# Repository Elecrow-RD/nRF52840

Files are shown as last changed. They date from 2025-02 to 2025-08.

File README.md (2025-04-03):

### File introduction: 

#### firmware: here is the LR1110, LR1121, SX1262 & LLCC68 firmware file; 

#### lora_development_board: here is supporting the development of different modules of the board schematic diagrams, the user can download and use their own; 

#### sendATcommands_new: here is the lora send commands code program;

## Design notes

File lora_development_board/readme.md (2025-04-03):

### Corresponding modules use corresponding development boards: 

##### LR1262&LRCC68: the corresponding development board is Transceiver Module Dev Board (without MCU)_V0.1_SCH; 

##### nRFLRxxxx: the corresponding development board is Transceiver Module Dev Board (with Transceiver Module Dev Board (with MCU)_V0.1.

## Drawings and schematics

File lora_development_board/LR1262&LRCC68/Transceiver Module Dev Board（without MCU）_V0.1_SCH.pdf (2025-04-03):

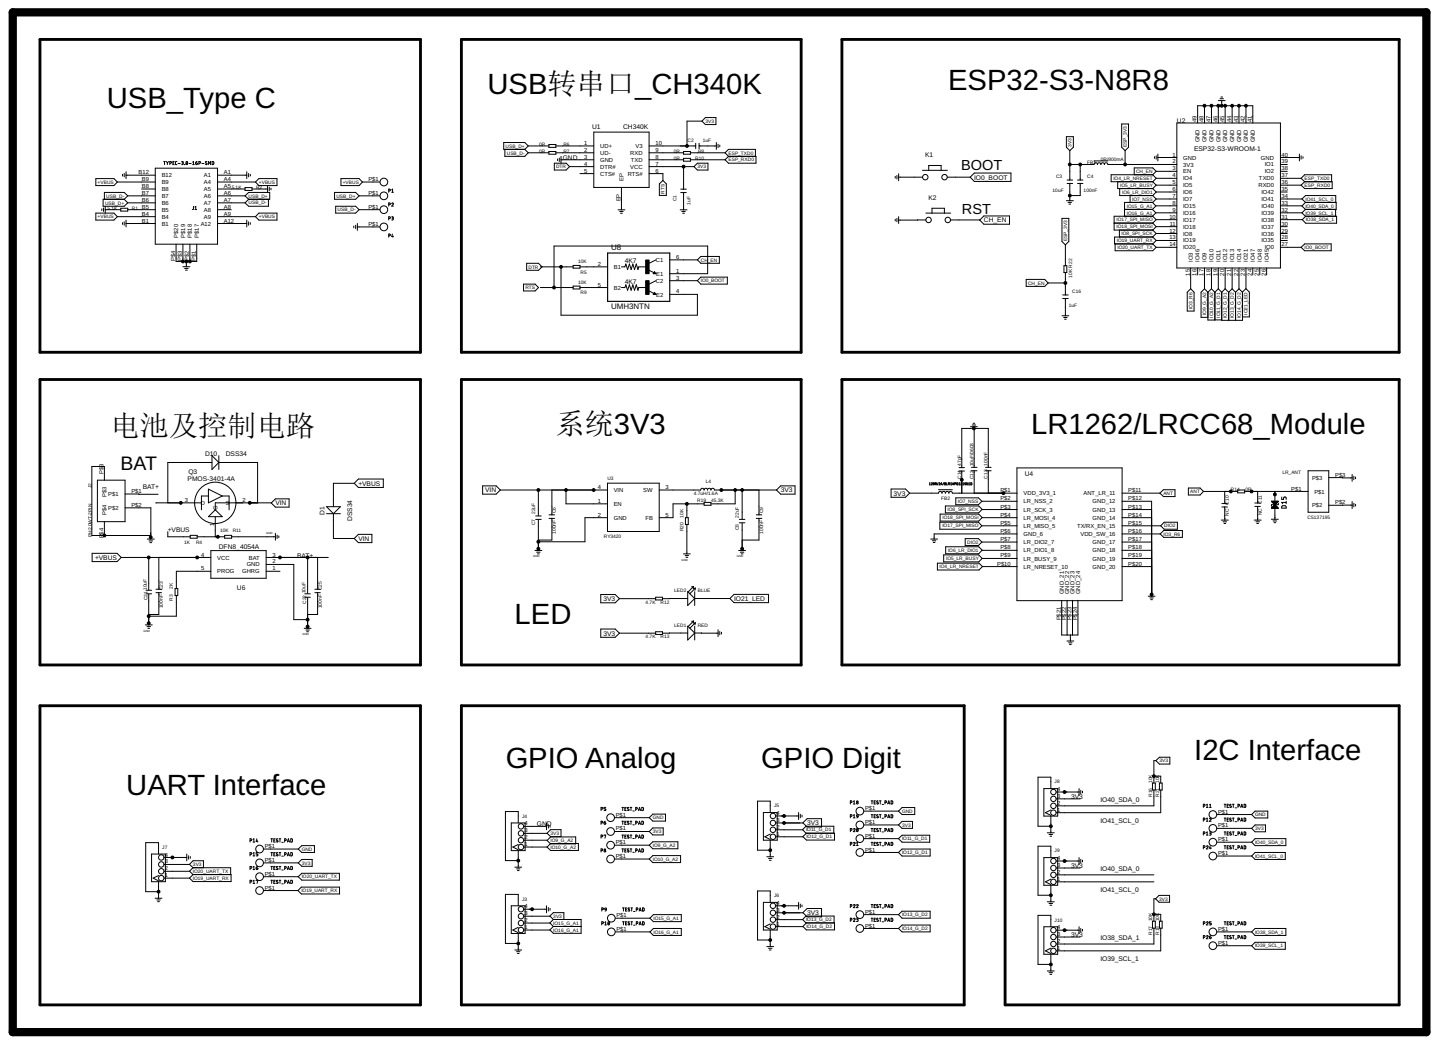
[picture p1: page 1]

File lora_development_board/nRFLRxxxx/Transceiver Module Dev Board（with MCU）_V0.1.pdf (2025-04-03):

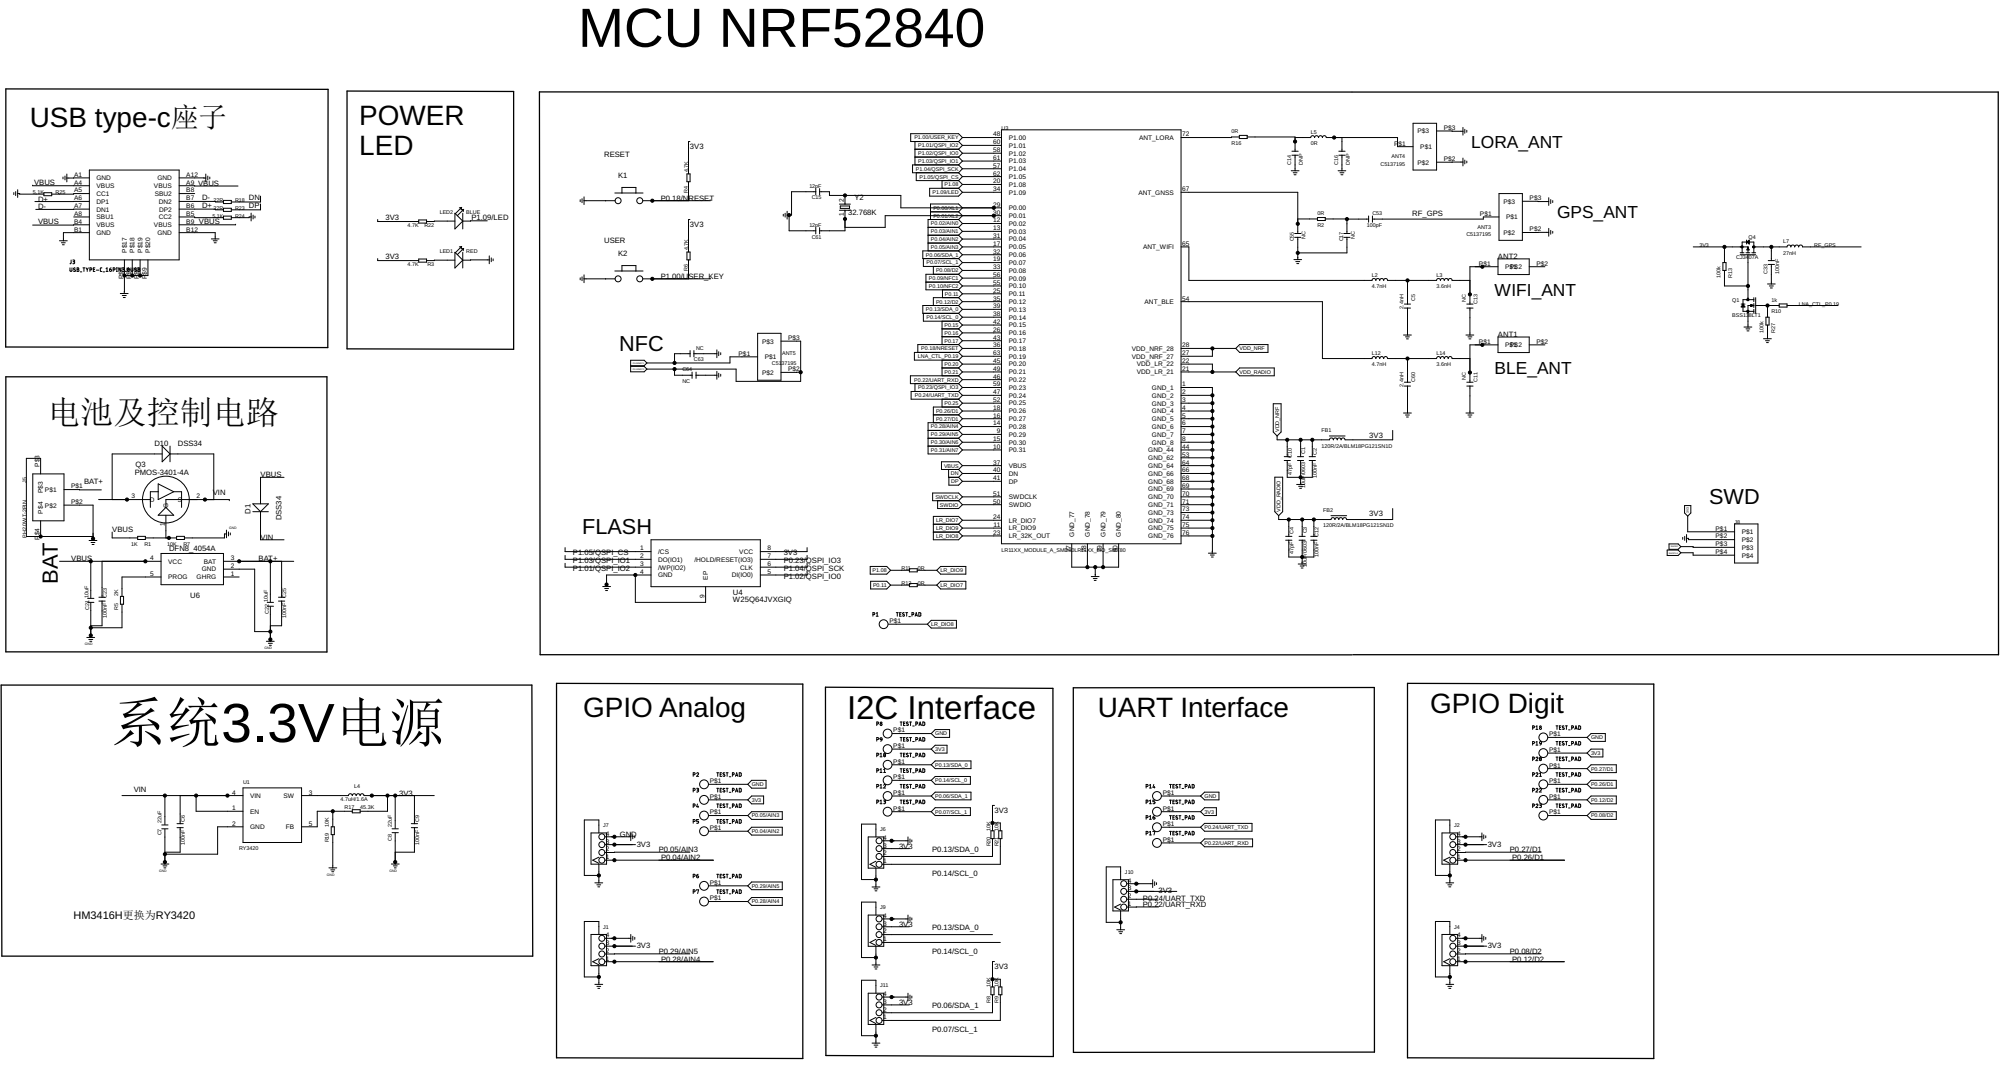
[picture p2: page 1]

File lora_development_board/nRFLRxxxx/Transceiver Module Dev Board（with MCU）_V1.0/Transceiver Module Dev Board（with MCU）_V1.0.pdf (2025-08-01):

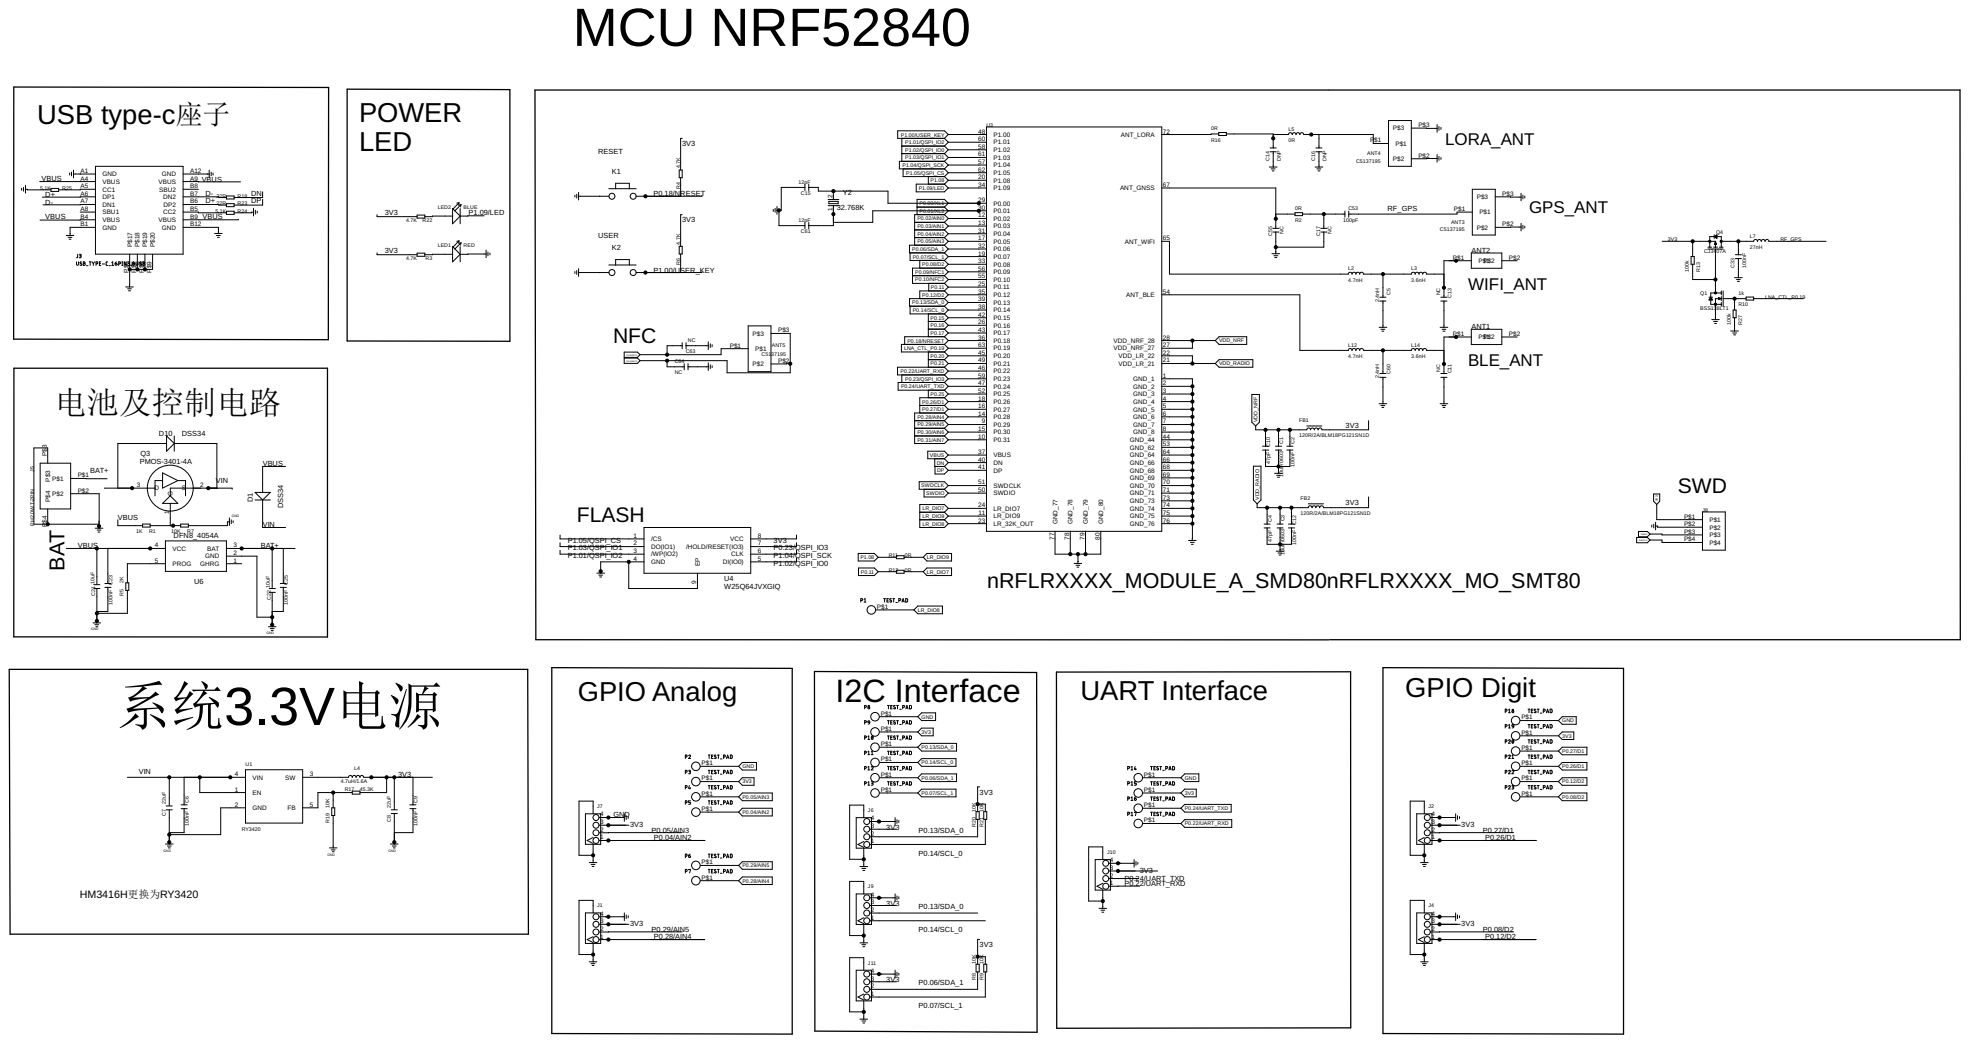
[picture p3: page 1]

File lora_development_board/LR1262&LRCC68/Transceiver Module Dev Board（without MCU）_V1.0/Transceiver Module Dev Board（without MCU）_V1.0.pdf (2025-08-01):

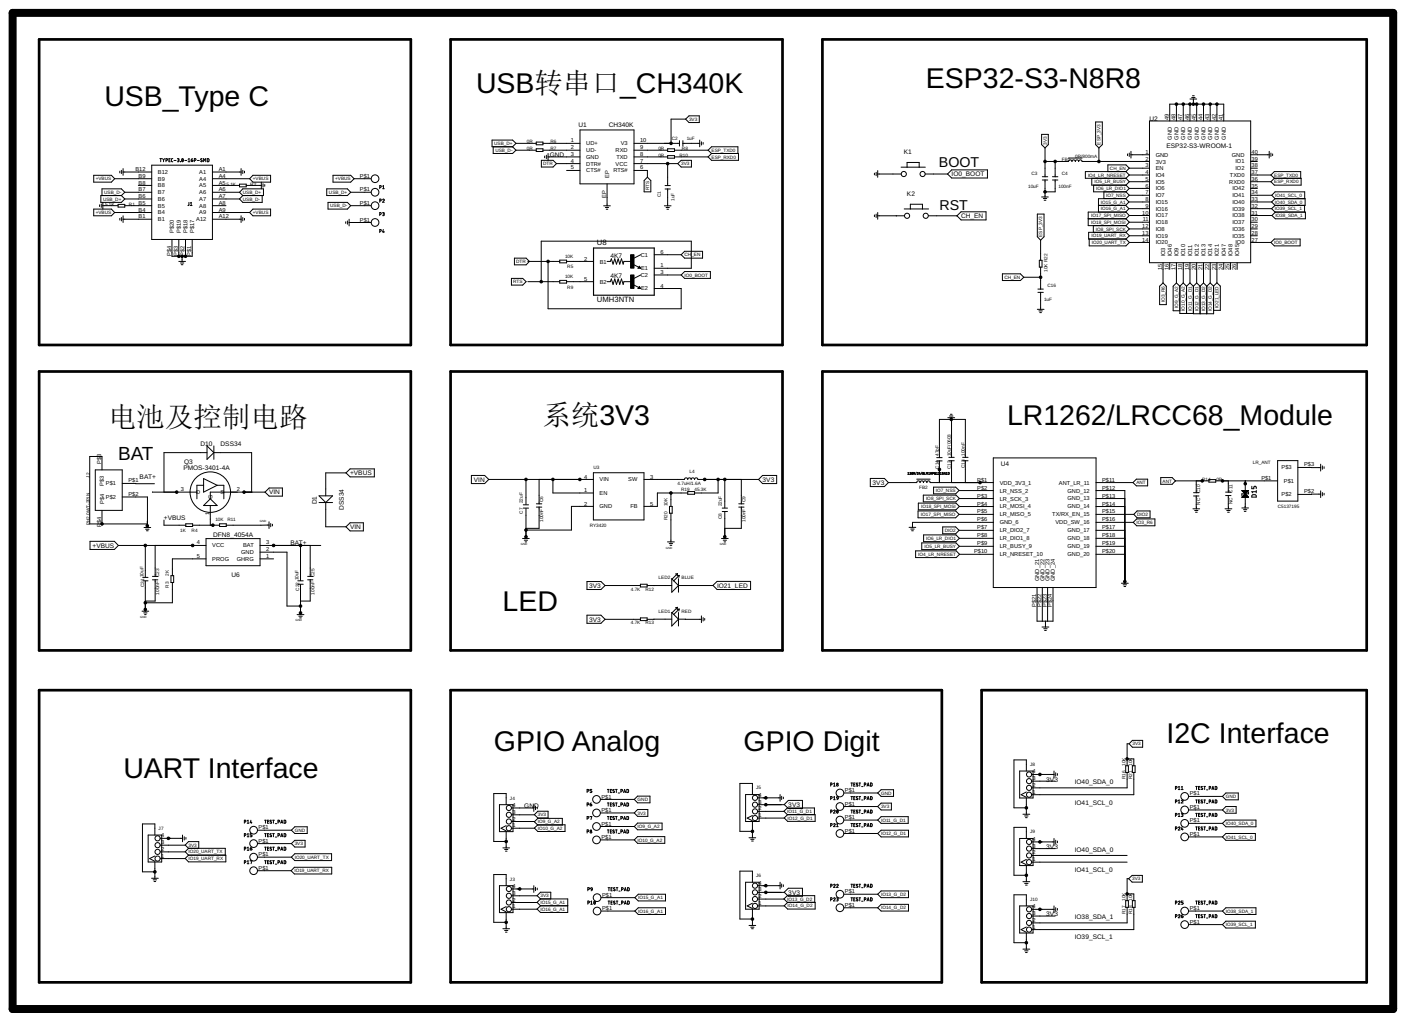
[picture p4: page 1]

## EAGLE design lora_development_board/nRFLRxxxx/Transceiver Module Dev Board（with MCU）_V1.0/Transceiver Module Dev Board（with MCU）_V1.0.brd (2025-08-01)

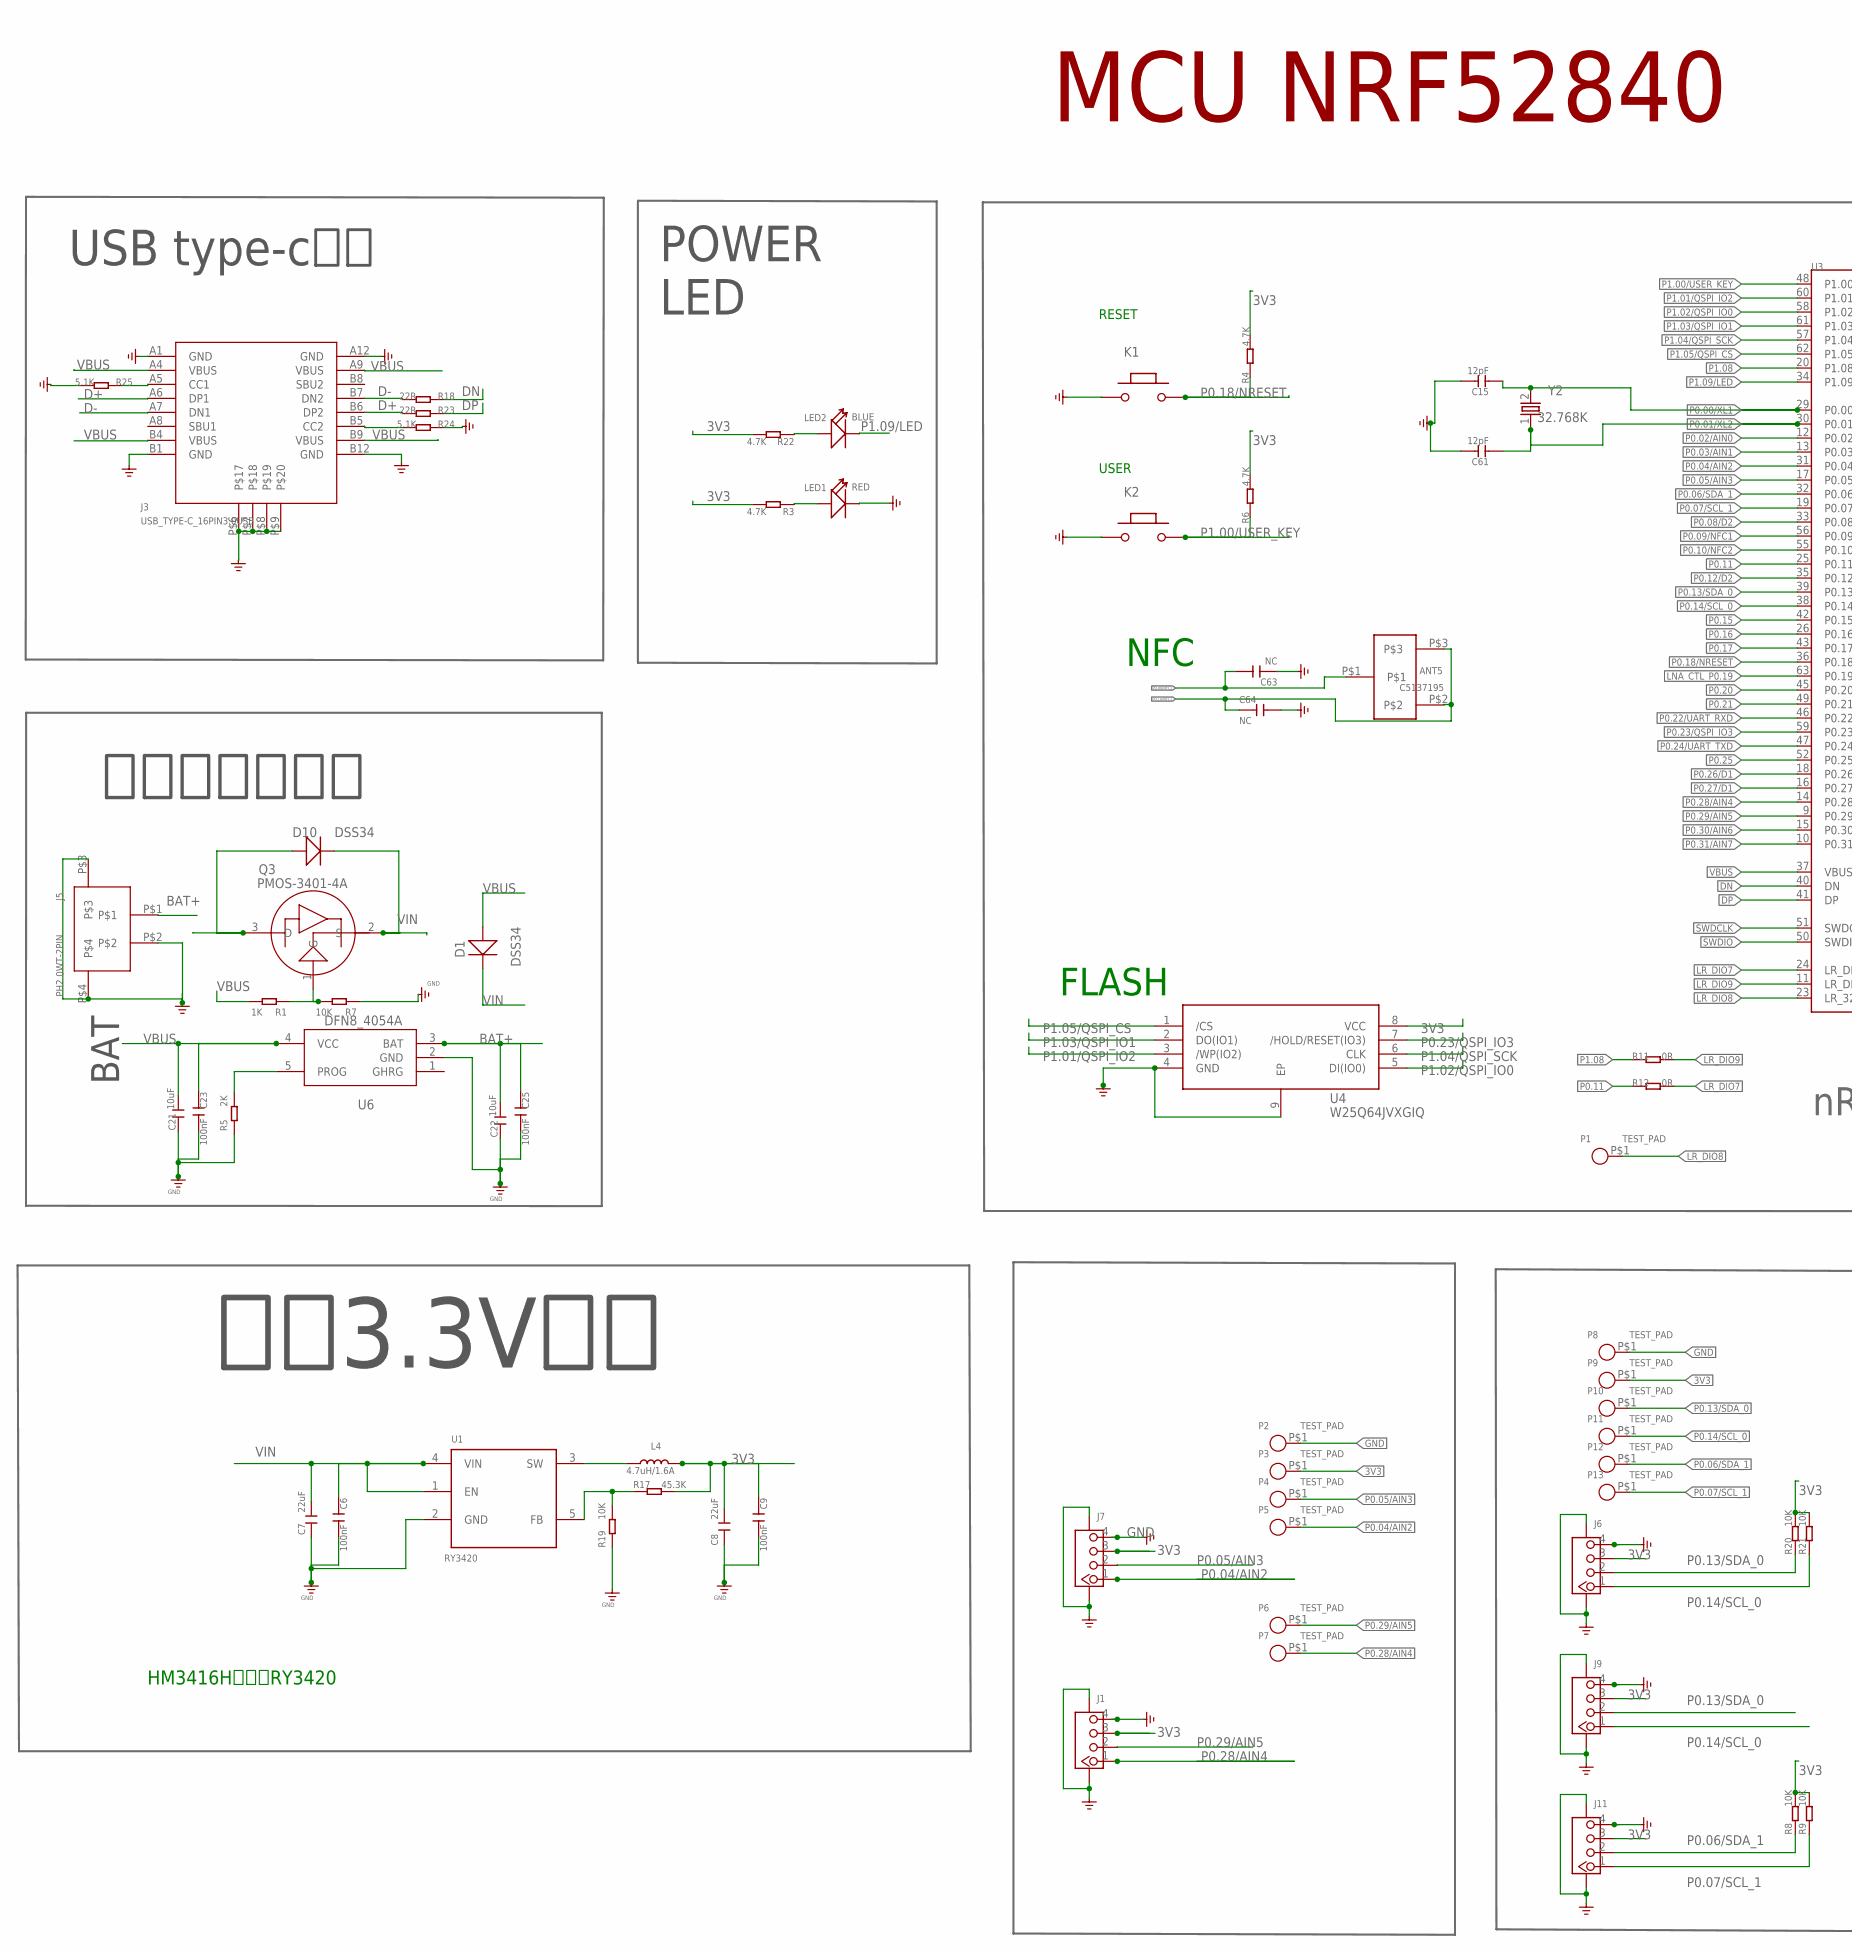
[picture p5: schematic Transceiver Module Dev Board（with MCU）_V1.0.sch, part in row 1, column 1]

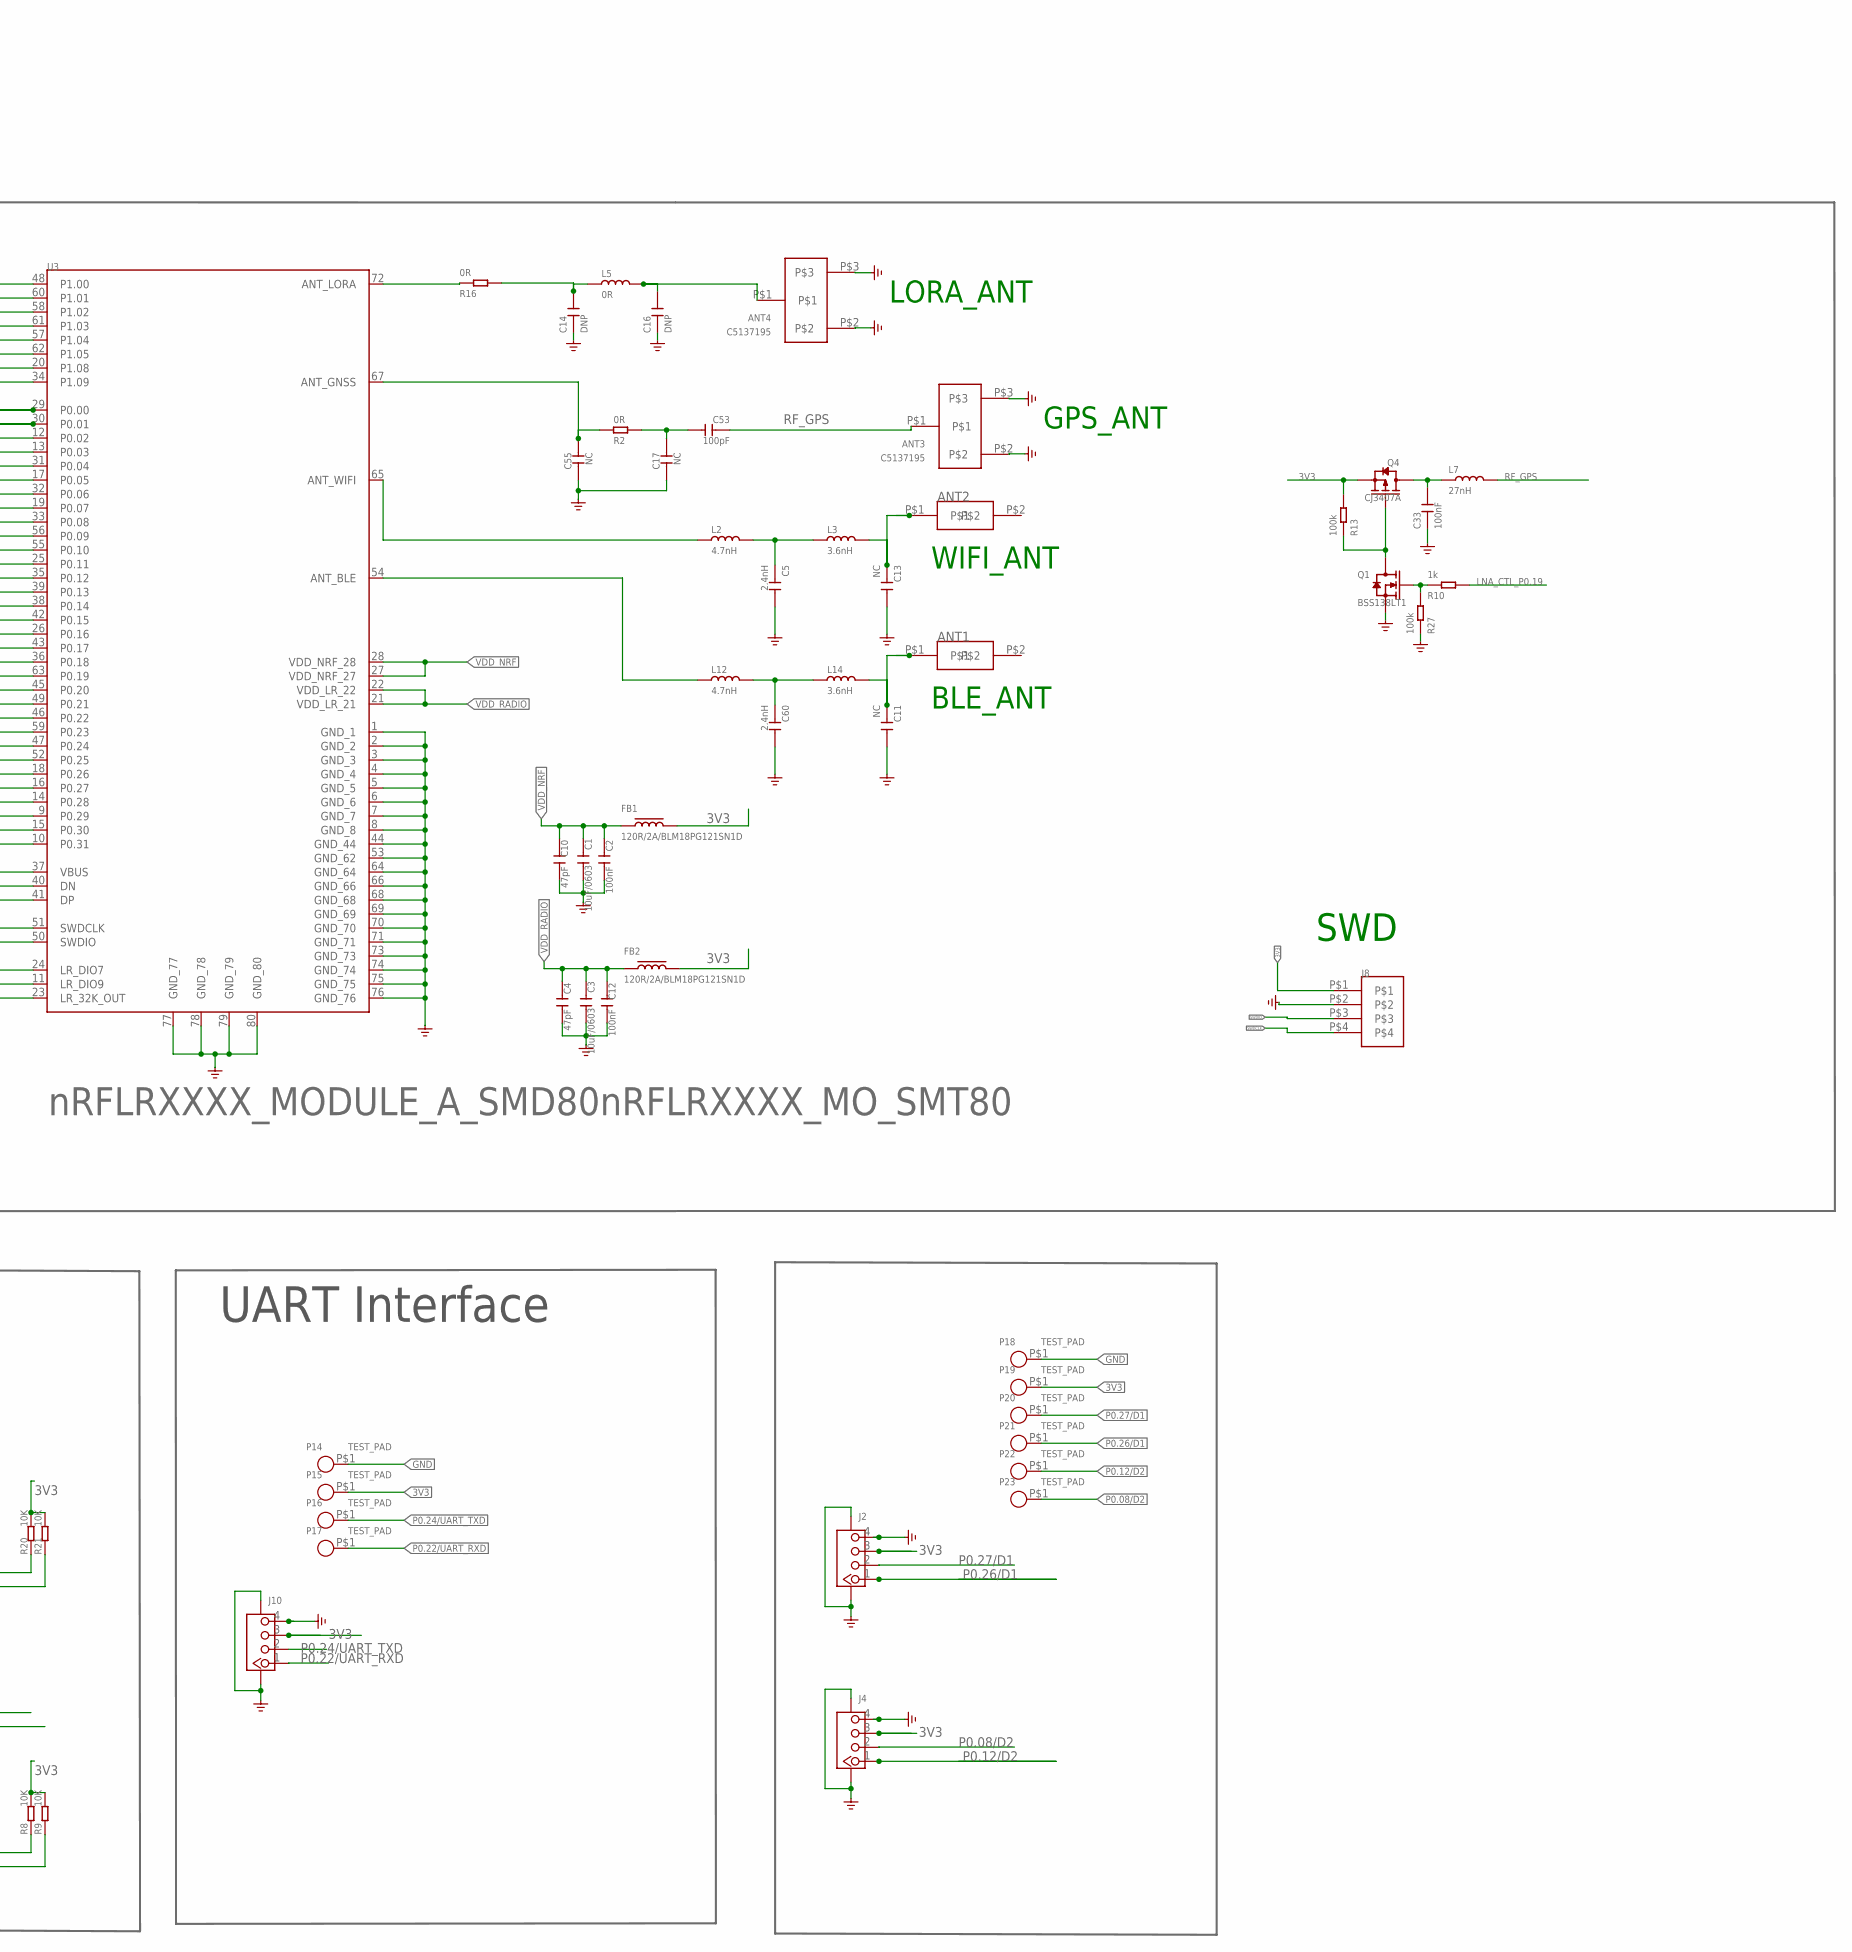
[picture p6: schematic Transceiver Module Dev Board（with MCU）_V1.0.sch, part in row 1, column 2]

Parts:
ANT1, ANT2: ANT2.4G_BLE; 2.4G_BLE
ANT3, ANT4, ANT5: C5137195; MYSELF_IPEX1
C1, C3: 10uF/0603; C0603
C2, C6, C9, C12, C23, C25, C33: 100nF; C0402
C4, C10: 47pF; C0402
C5, C60: 2.4nH; DISCRETE-NEW_C0402
C7, C8: 22uF; 0603
C11, C13, C17, C55, C63, C64: NC; DISCRETE-NEW_C0402
C14, C16: DNP; C0402
C15, C61: 12pF; DISCRETE-NEW_C0402
C21, C22: 10uF; 0402
C53: 100pF; DISCRETE-NEW_C0402
D1, D10: DSS34; D_SOD123FL
FB1, FB2: 120R/2A/BLM18PG121SN1D; L0603
J1, J2, J4, J6, J7, J9, J10, J11: CONNECTOR_TWIG-4P-2.0-SMD-FEMALE-REINFORCE90D; CONNECTOR_4P-SMD-2.0-90D
J3: USB_TYPE-C_16PIN3.0USB; KEVIN_3.0TYPEC-SMD
J5: PH2.0WT-2PIN
J8: 2.0MM-4P
K1, K2: BUTTON; 157SW
L2, L12: 4.7nH; XADOW-GPS-V2_DISCRETE-NEW_L0402
L3, L14: 3.6nH; XADOW-GPS-V2_DISCRETE-NEW_L0402
L4: 4.7uH/1.6A; A9G_DISCRETE_L0805
L5: 0R; L0402
L7: 27nH; L0402
LED1: RED; DISCRETE_LED-0603
LED2: BLUE; DISCRETE_LED-0603
P1, P2, P3, P4, P5, P6, P7, P8, P9, P10, P11, P12, P13, P14, P15, P16, P17, P18, P19, P20, P21, P22, P23: TEST_PAD; TEST_PAD-1.5MM
Q1: BSS138LT1; SOT-323
Q3: PMOS-3401-4A; SOT-23
Q4: CJ3407A; SOT-323
R1: 1K; 0402
R2, R16: 0R; DISCRETE-NEW_R0402
R3, R22: 4.7K; 0402
R4, R6: 4.7K; DISCRETE_R0603
R5: 2K; 0402
R7, R8, R9, R19, R20, R21: 10K; 0402
R10: 1k; R0402
R11, R12: 0R; R0402
R13, R27: 100k; R0402
R17: 45.3K; 0402
R18, R23: 22R; 0402
R24, R25: 5.1K; 0402
U1: RY3420; CROWBOT_-V1.0-20220525_A_XBJ_SOT23-5
U3: nRFLRXXXX_MODULE_A_SMD80nRFLRXXXX_MO_SMT80; LR11XX_MO_A_SMD80
U4: W25Q64JVXGIQ; XSON-EP(4×4)
U6: DFN8_4054A; DFN8_SOP23-5
Y2: 32.768K; NORDIC_NRF_XTAL_3215_N

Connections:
3V3: C8.2, C9.1, FB1.2, FB2.2, J1.3, J2.3, J4.3, J6.3, J7.3, J8.P$1, J9.3, J10.3, J11.3, L4.2, P3.P$1, P9.P$1, P15.P$1, P19.P$1, Q4.2 (S), R3.2, R4.2, R6.2, R8.2, R9.2, R13.2, R17.2, R20.2, R21.2, R22.2, U4.8 (VCC)
BAT+: C22.2, C25.1, D10.+, J5.P$1, Q3.3 (D), U6.3 (BAT)
D+: J3.A6 (DP1), J3.B6 (DP2), R23.2
D-: J3.A7 (DN1), J3.B7 (DN2), R18.2
DN: R18.1, U3.40 (DN)
DP: R23.1, U3.41 (DP)
GND: ANT3.P$2, ANT3.P$3, ANT4.P$2, ANT4.P$3, C1.2, C2.2, C3.2, C4.2, C5.2, C6.2, C7.1, C8.1, C9.2, C10.2, C11.2, C12.2, C13.2, C14.1, C15.2, C16.1, C17.2, C21.1, C22.1, C23.2, C25.2, C33.1, C55.2, C60.2, C61.2, C63.1, C64.2, J1.4, J1.SS1, J1.SS2, J2.4, J2.SS1, J2.SS2, J3.A1 (GND), J3.A12 (GND), J3.B1 (GND), J3.B12 (GND), J3.P$6, J3.P$7, J3.P$8, J3.P$9, J4.4, J4.SS1, J4.SS2, J5.P$2, J5.P$3, J5.P$4, J6.4, J6.SS1, J6.SS2, J7.4, J7.SS1, J7.SS2, J8.P$2, J9.4, J9.SS1, J9.SS2, J10.4, J10.SS1, J10.SS2, J11.4, J11.SS1, J11.SS2, K1.1, K2.1, LED1.-, P2.P$1, P8.P$1, P14.P$1, P18.P$1, Q1.2 (S), R5.1, R7.1, R19.1, R24.1, R25.2, R27.1, U1.2 (GND), U3.1 (GND_1), U3.2 (GND_2), U3.3 (GND_3), U3.4 (GND_4), U3.5 (GND_5), U3.6 (GND_6), U3.7 (GND_7), U3.8 (GND_8), U3.44 (GND_44), U3.53 (GND_62), U3.64 (GND_64), U3.66 (GND_66), U3.68 (GND_68), U3.69 (GND_69), U3.70 (GND_70), U3.71 (GND_71), U3.73 (GND_73), U3.74 (GND_74), U3.75 (GND_75), U3.76 (GND_76), U3.77 (GND_77), U3.78 (GND_78), U3.79 (GND_79), U3.80 (GND_80), U4.4 (GND), U4.9 (EP), U6.2 (GND)
LNA_CTL_P0.19: R10.2, U3.63 (P0.19)
LR_DIO7: R12.2, U3.24 (LR_DIO7)
LR_DIO8: P1.P$1, U3.23 (LR_32K_OUT)
LR_DIO9: R11.2, U3.11 (LR_DIO9)
unnamed: LED2.+, R22.1
unnamed: L12.1, U3.54 (ANT_BLE)
unnamed: C5.1, L2.2, L3.1
unnamed: ANT2.P$1, C13.1, L3.2
unnamed: L2.1, U3.65 (ANT_WIFI)
unnamed: J3.B5 (CC2), R24.2
unnamed: C55.1, R2.1, U3.67 (ANT_GNSS)
unnamed: R16.1, U3.72 (ANT_LORA)
unnamed: LED1.+, R3.1
unnamed: Q3.1 (G), R1.1, R7.2
unnamed: J3.A5 (CC1), R25.1
unnamed: L4.1, U1.3 (SW)
unnamed: C14.2, L5.1, R16.2
unnamed: ANT4.P$1, C16.2, L5.2
unnamed: Q1.3 (D), Q4.1 (G), R13.1
unnamed: Q1.1 (G), R10.1, R27.2
unnamed: R17.1, R19.2, U1.5 (FB)
unnamed: R5.2, U6.5 (PROG)
unnamed: C33.2, L7.1, Q4.3 (D)
unnamed: C17.1, C53.2, R2.2
unnamed: C60.1, L12.2, L14.1
unnamed: ANT1.P$1, C11.1, L14.2
P0.00/XL1: C15.1, U3.29 (P0.00), Y2.2
P0.01/XL2: C61.1, U3.30 (P0.01), Y2.1
P0.02/AIN0: U3.12 (P0.02)
P0.03/AIN1: U3.13 (P0.03)
P0.04/AIN2: J7.1, P5.P$1, U3.31 (P0.04)
P0.05/AIN3: J7.2, P4.P$1, U3.17 (P0.05)
P0.06/SDA_1: J11.2, P12.P$1, R8.1, U3.32 (P0.06)
P0.07/SCL_1: J11.1, P13.P$1, R9.1, U3.19 (P0.07)
P0.08/D2: J4.2, P23.P$1, U3.33 (P0.08)
P0.09/NFC1: ANT5.P$1, C63.2, U3.56 (P0.09)
P0.10/NFC2: ANT5.P$2, ANT5.P$3, C64.1, U3.55 (P0.10)
P0.11: R12.1, U3.25 (P0.11)
P0.12/D2: J4.1, P22.P$1, U3.35 (P0.12)
P0.13/SDA_0: J6.2, J9.2, P10.P$1, R20.1, U3.39 (P0.13)
P0.14/SCL_0: J6.1, J9.1, P11.P$1, R21.1, U3.38 (P0.14)
P0.15: U3.42 (P0.15)
P0.16: U3.26 (P0.16)
P0.17: U3.43 (P0.17)
P0.18/NRESET: K1.2, R4.1, U3.36 (P0.18)
P0.20: U3.45 (P0.20)
P0.21: U3.49 (P0.21)
P0.22/UART_RXD: J10.1, P17.P$1, U3.46 (P0.22)
P0.23/QSPI_IO3: U3.59 (P0.23), U4.7 (/HOLD/RESET(IO3))
P0.24/UART_TXD: J10.2, P16.P$1, U3.47 (P0.24)
P0.25: U3.52 (P0.25)
P0.26/D1: J2.1, P21.P$1, U3.18 (P0.26)
P0.27/D1: J2.2, P20.P$1, U3.16 (P0.27)
P0.28/AIN4: J1.1, P7.P$1, U3.14 (P0.28)
P0.29/AIN5: J1.2, P6.P$1, U3.9 (P0.29)
P0.30/AIN6: U3.15 (P0.30)
P0.31/AIN7: U3.10 (P0.31)
P1.00/USER_KEY: K2.2, R6.1, U3.48 (P1.00)
P1.01/QSPI_IO2: U3.60 (P1.01), U4.3 (/WP(IO2))
P1.02/QSPI_IO0: U3.58 (P1.02), U4.5 (DI(IO0))
P1.03/QSPI_IO1: U3.61 (P1.03), U4.2 (DO(IO1))
P1.04/QSPI_SCK: U3.57 (P1.04), U4.6 (CLK)
P1.05/QSPI_CS: U3.62 (P1.05), U4.1 (/CS)
P1.08: R11.1, U3.20 (P1.08)
P1.09/LED: LED2.-, U3.34 (P1.09)
RF_GPS: ANT3.P$1, C53.1, L7.2
SWDCLK: J8.P$4, U3.51 (SWDCLK)
SWDIO: J8.P$3, U3.50 (SWDIO)
VBUS: C21.2, C23.1, D1.+, J3.A4 (VBUS), J3.A9 (VBUS), J3.B4 (VBUS), J3.B9 (VBUS), R1.2, U3.37 (VBUS), U6.4 (VCC)
VDD_NRF: C1.1, C2.1, C10.1, FB1.1, U3.27 (VDD_NRF_27), U3.28 (VDD_NRF_28)
VDD_RADIO: C3.1, C4.1, C12.1, FB2.1, U3.21 (VDD_LR_21), U3.22 (VDD_LR_22)
VIN: C6.1, C7.2, D1.-, D10.-, Q3.2 (S), U1.1 (EN), U1.4 (VIN)

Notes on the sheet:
系统3.3V电源
UART Interface
MCU NRF52840
USB type-c座子
电池及控制电路
POWER LED
HM3416H更换为RY3420
BAT
FLASH
BLE_ANT
RESET
USER
WIFI_ANT
SWD
GPS_ANT
LORA_ANT
NFC

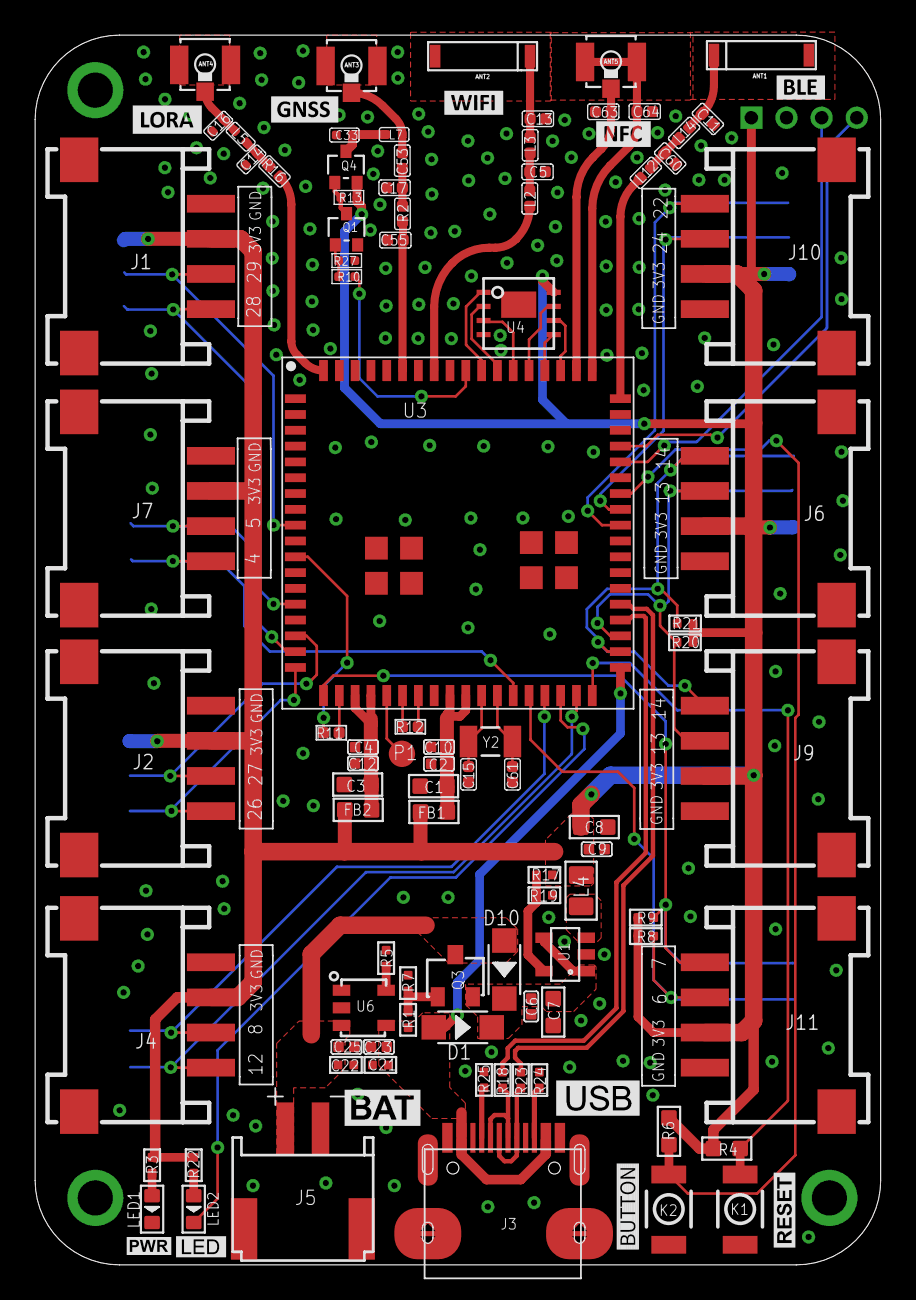
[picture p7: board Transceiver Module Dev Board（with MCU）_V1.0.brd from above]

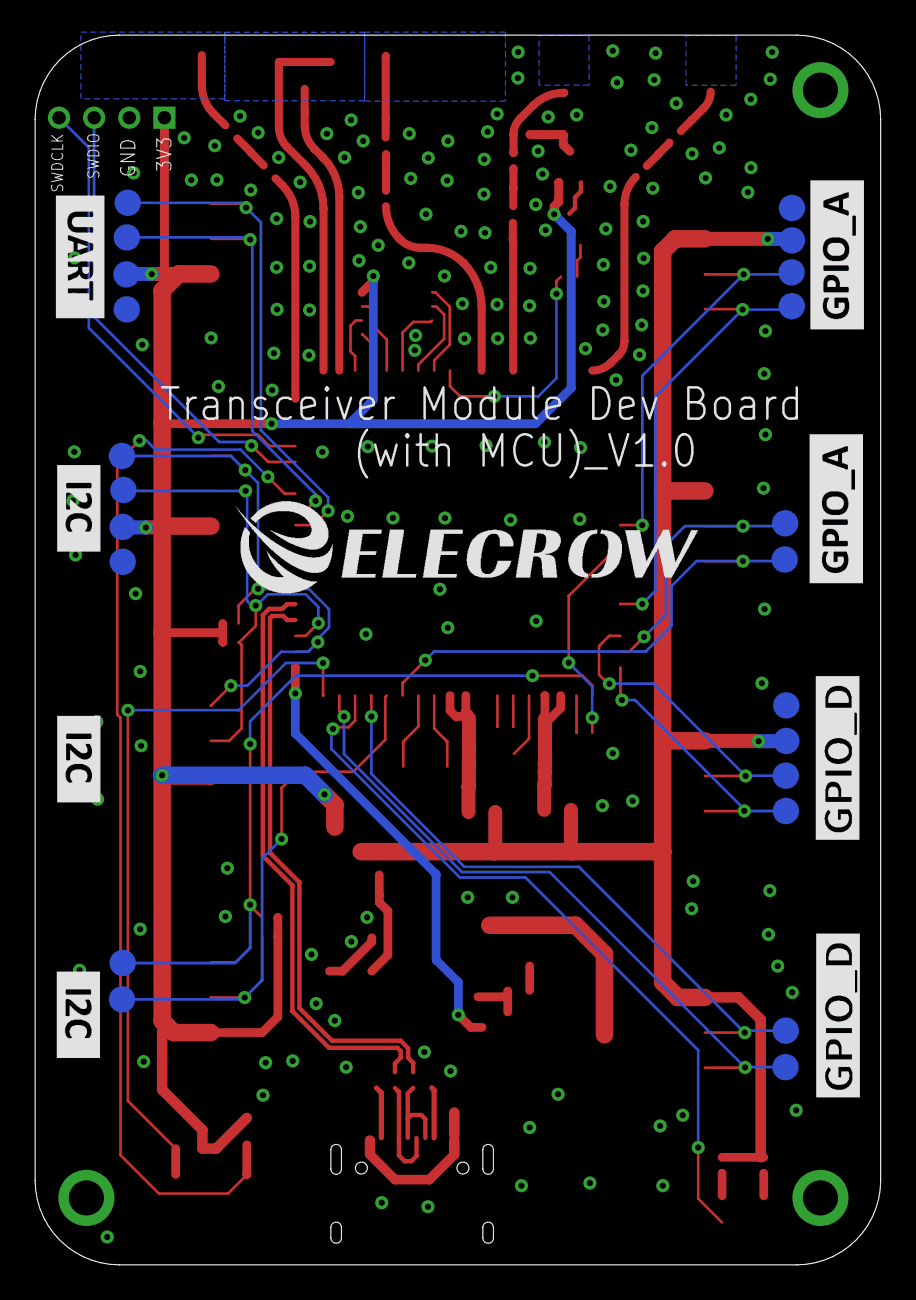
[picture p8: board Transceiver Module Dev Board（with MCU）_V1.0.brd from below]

Board: 2 copper layers, 48.1 x 70.0 mm, 114 parts (22 on the bottom side), 69 nets.

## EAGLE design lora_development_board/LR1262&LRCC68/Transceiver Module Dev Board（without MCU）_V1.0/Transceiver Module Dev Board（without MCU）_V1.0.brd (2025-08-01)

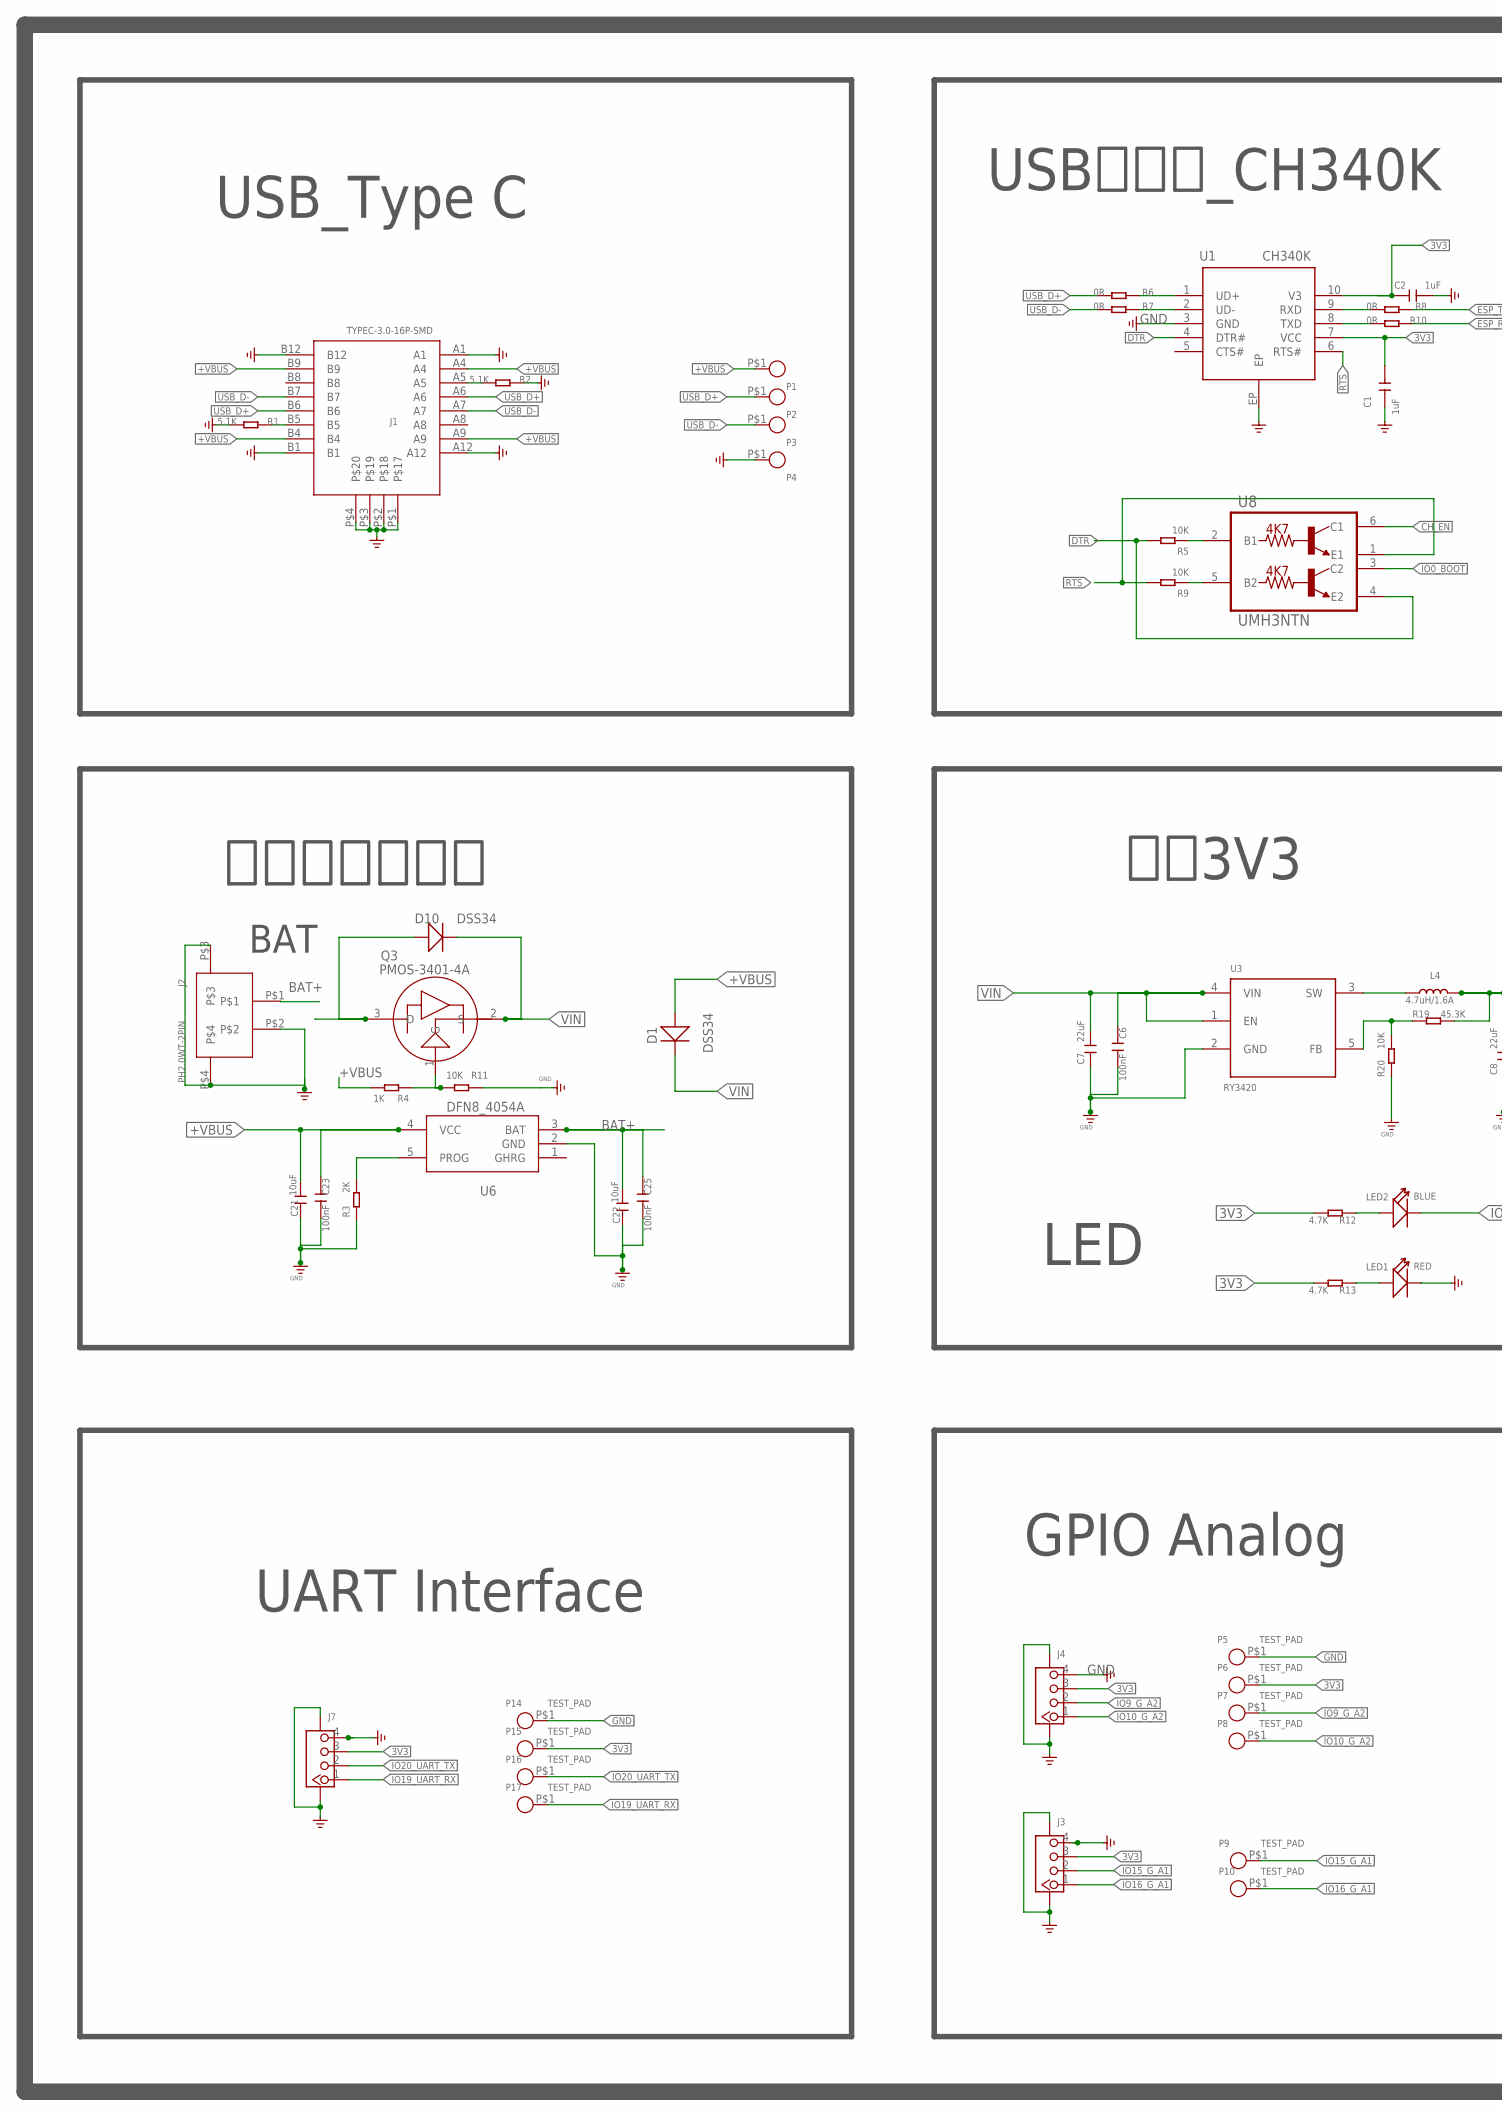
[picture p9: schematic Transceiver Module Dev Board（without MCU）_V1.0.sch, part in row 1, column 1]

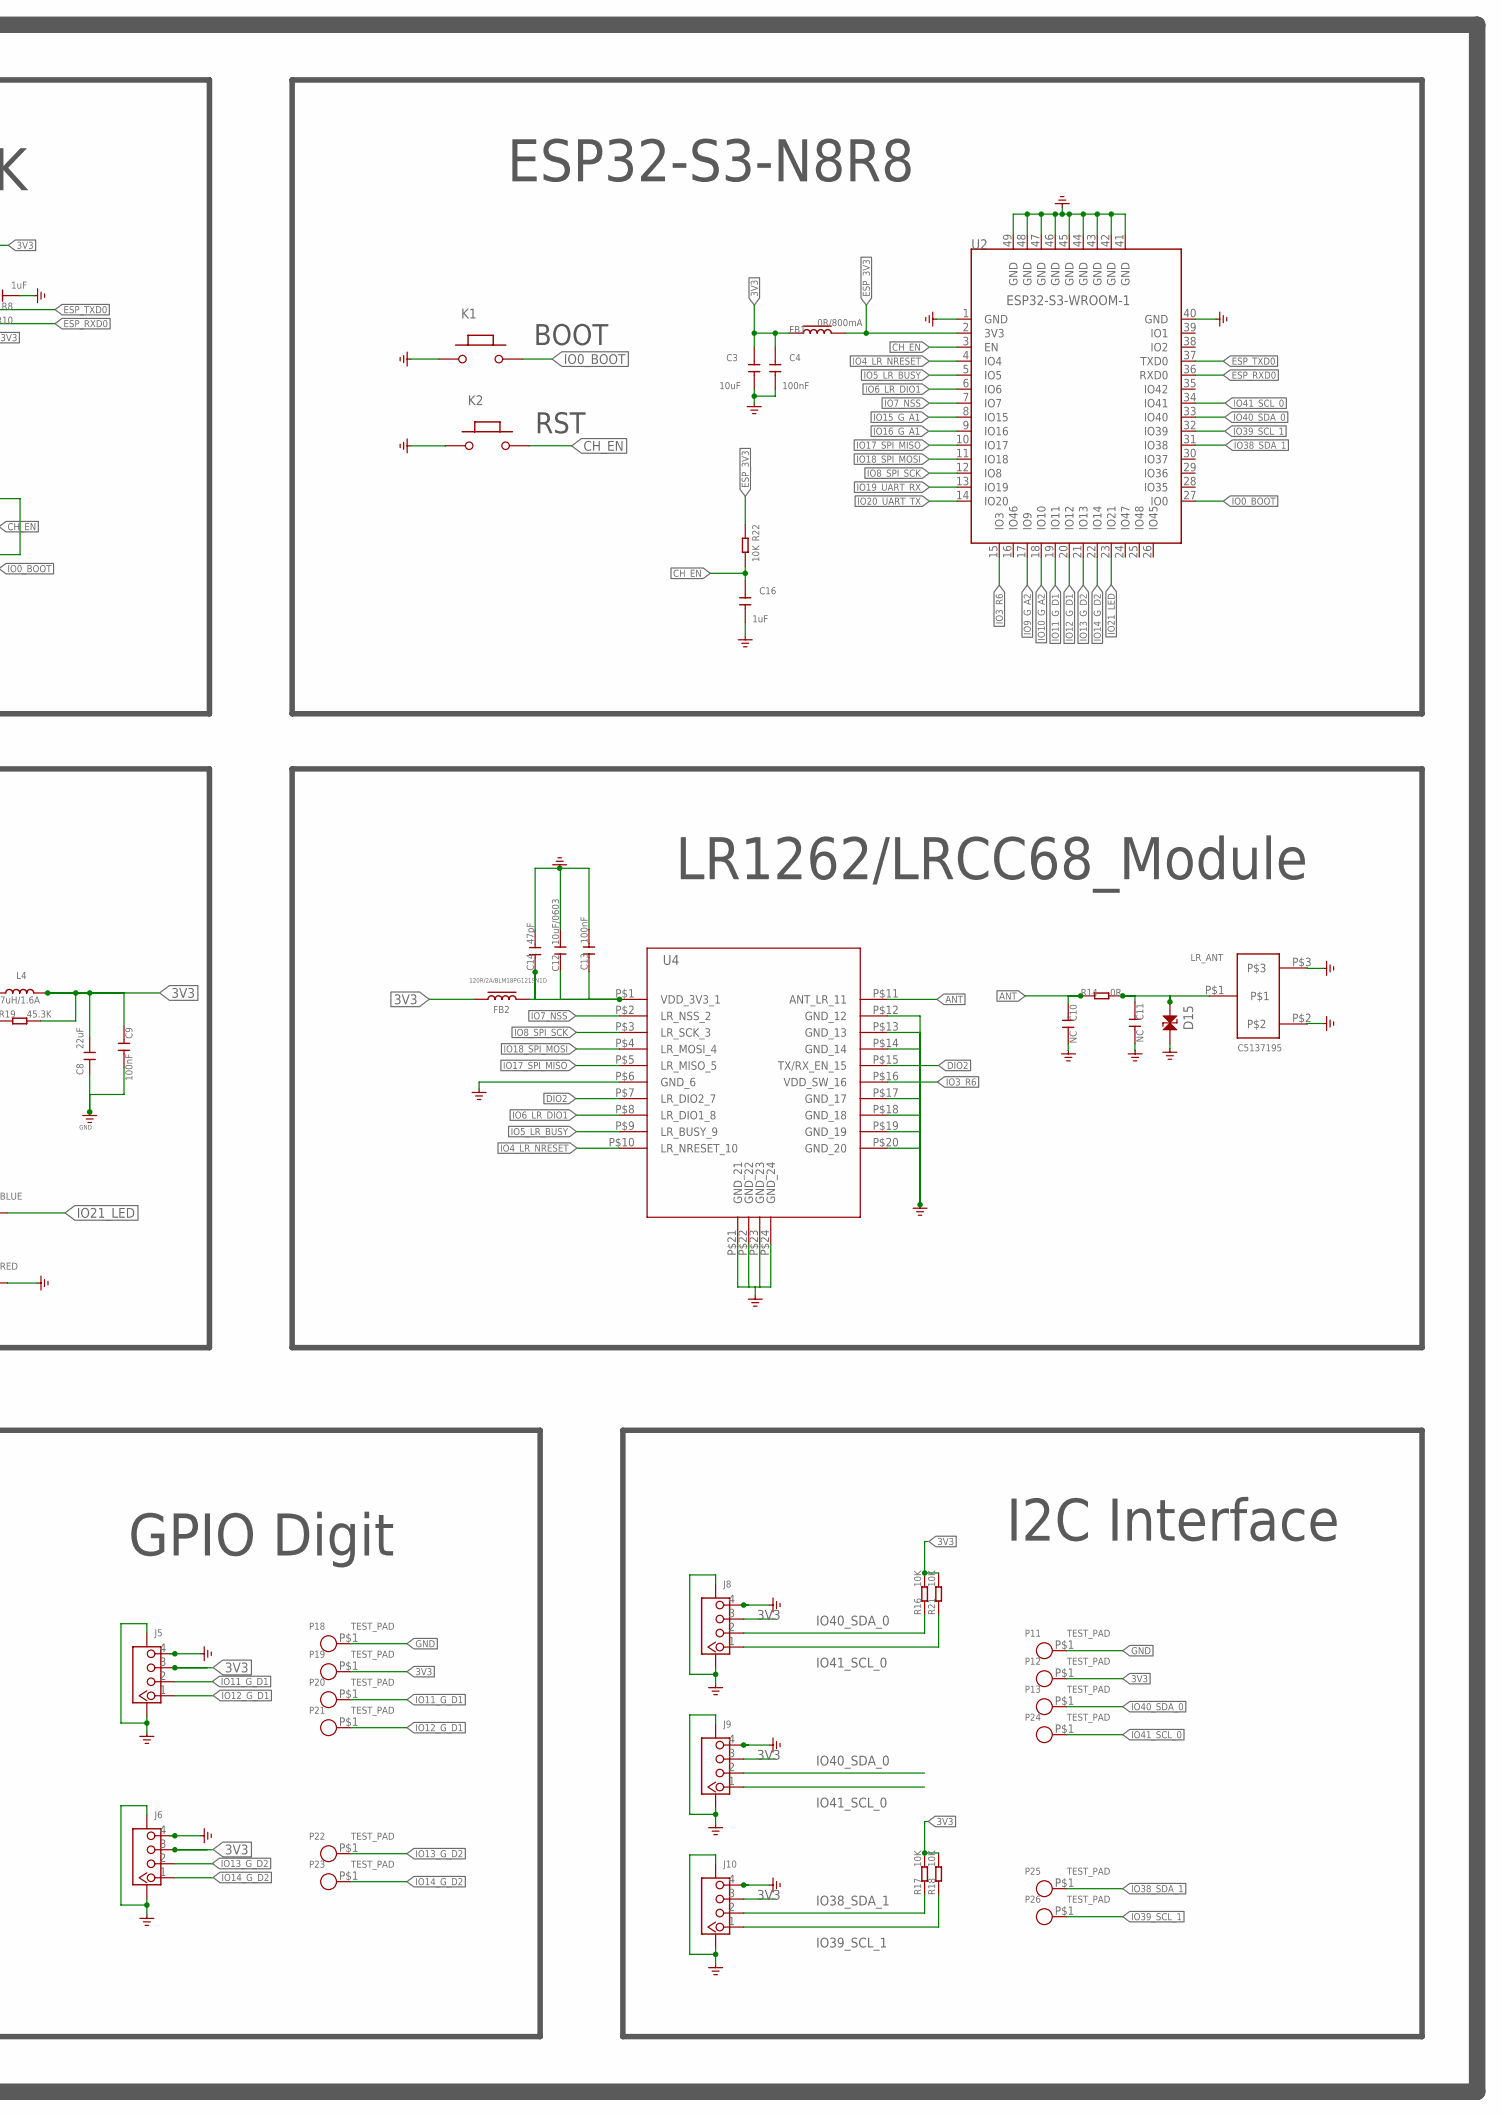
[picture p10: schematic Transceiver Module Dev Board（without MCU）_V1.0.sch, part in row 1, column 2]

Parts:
C1, C2, C16: 1uF; C0603
C3: 10uF; C0603
C4: 100nF; C0603
C6, C9, C13, C23, C25: 100nF; C0402
C7, C8: 22uF; 0603
C10, C11: NC; C0402
C12: 10uF/0603; C0603
C14: 47pF; C0402
C21, C22: 10uF; 0402
D1, D10: DSS34; D_SOD123FL
D15: LXES15AAA1-153; 0402-ESD
FB1: 0R/800mA; L0603
FB2: 120R/2A/BLM18PG121SN1D; L0603
J1: TYPEC-3.0-16P-SMD; USB-3.0TYPEC-SMD
J2: PH2.0WT-2PIN
J3, J4, J5, J6, J7, J8, J9, J10: CONNECTOR_TWIG-4P-2.0-SMD-FEMALE-REINFORCE90D; CONNECTOR_4P-SMD-2.0-90D
K1, K2: BUTTON; 157SW
L4: 4.7uH/1.6A; A9G_DISCRETE_L0805
LED1: RED; DISCRETE_LED-0603
LED2: BLUE; DISCRETE_LED-0603
LR_ANT: C5137195; MYSELF_IPEX1
P1, P2, P3, P4: TEST_PADPAD-1.5MM; TEST_PAD-1.5MM
P5, P6, P7, P8, P9, P10, P11, P12, P13, P14, P15, P16, P17, P18, P19, P20, P21, P22, P23, P24, P25, P26: TEST_PAD; TEST_PAD-1.5MM
Q3: PMOS-3401-4A; SOT-23
R1, R2: 5.1K; R0603-SP
R3: 2K; 0402
R4: 1K; 0402
R5, R9, R22: 10K; R0603-SP
R6, R7, R8, R10: 0R; R0603-SP
R11, R16, R17, R18, R20, R21: 10K; 0402
R12, R13: 4.7K; 0402
R14: 0R; R0402
R19: 45.3K; 0402
U1: CH340K; ESOP-10-EP-150MIL
U2: ESP32-S3-WROOM-1; ESP32-S3-WROOM-1-SMD41
U3: RY3420; CROWBOT_-V1.0-20220525_A_XBJ_SOT23-5
U4: LR1262_LRCC68_MD_1010MM; LR1262_LRCC68_MD_10*10MM
U6: DFN8_4054A; DFN8_SOP23-5
U8: UMH3NTN; SOP65P210X100-6N

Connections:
3V3: C1.2, C2.2, C3.2, C4.2, C8.2, C9.1, FB1.1, FB2.1, J3.3, J4.3, J5.3, J6.3, J7.3, J8.3, J9.3, J10.3, L4.2, P6.P$1, P12.P$1, P15.P$1, P19.P$1, R12.2, R13.2, R16.2, R17.2, R18.2, R19.2, R21.2, U1.7 (VCC), U1.10 (V3)
+VBUS: C21.2, C23.1, D1.+, J1.A4, J1.A9, J1.B4, J1.B9, P1.P$1, R4.2, U6.4 (VCC)
ANT: C10.1, R14.1, U4.P$11 (ANT_LR_11)
BAT+: C22.2, C25.1, D10.+, J2.P$1, Q3.3 (D), U6.3 (BAT)
CH_EN: C16.2, K2.2, R22.2, U2.3 (EN), U8.6 (C1)
DIO2: U4.P$7 (LR_DIO2_7), U4.P$15 (TX/RX_EN_15)
DTR: R5.2, U1.4 (DTR#), U8.4 (E2)
ESP_3V3: FB1.2, R22.1, U2.2 (3V3)
ESP_RXD0: R10.1, U2.36 (RXD0)
ESP_TXD0: R8.1, U2.37 (TXD0)
GND: C1.1, C2.1, C3.1, C4.1, C6.2, C7.1, C8.1, C9.2, C10.2, C11.2, C12.2, C13.2, C14.2, C16.1, C21.1, C22.1, C23.2, C25.2, D15.1, J1.A1, J1.A12, J1.B1, J1.B12, J1.P$1, J1.P$2, J1.P$3, J1.P$4, J2.P$2, J2.P$3, J2.P$4, J3.4, J3.SS1, J3.SS2, J4.4, J4.SS1, J4.SS2, J5.4, J5.SS1, J5.SS2, J6.4, J6.SS1, J6.SS2, J7.4, J7.SS1, J7.SS2, J8.4, J8.SS1, J8.SS2, J9.4, J9.SS1, J9.SS2, J10.4, J10.SS1, J10.SS2, K1.1, K2.1, LED1.-, LR_ANT.P$2, LR_ANT.P$3, P4.P$1, P5.P$1, P11.P$1, P14.P$1, P18.P$1, R1.2, R2.1, R3.1, R11.1, R20.1, U1.3 (GND), U1.EP, U2.1 (GND), U2.40 (GND), U2.41 (GND), U2.42 (GND), U2.43 (GND), U2.44 (GND), U2.45 (GND), U2.46 (GND), U2.47 (GND), U2.48 (GND), U2.49 (GND), U3.2 (GND), U4.P$6 (GND_6), U4.P$12 (GND_12), U4.P$13 (GND_13), U4.P$14 (GND_14), U4.P$17 (GND_17), U4.P$18 (GND_18), U4.P$19 (GND_19), U4.P$20 (GND_20), U4.P$21 (GND_21), U4.P$22 (GND_22), U4.P$23 (GND_23), U4.P$24 (GND_24), U6.2 (GND)
IO0_BOOT: K1.2, U2.27 (IO0), U8.3 (C2)
IO3_R6: U2.15 (IO3), U4.P$16 (VDD_SW_16)
IO4_LR_NRESET: U2.4 (IO4), U4.P$10 (LR_NRESET_10)
IO5_LR_BUSY: U2.5 (IO5), U4.P$9 (LR_BUSY_9)
IO6_LR_DIO1: U2.6 (IO6), U4.P$8 (LR_DIO1_8)
IO7_NSS: U2.7 (IO7), U4.P$2 (LR_NSS_2)
IO8_SPI_SCK: U2.12 (IO8), U4.P$3 (LR_SCK_3)
IO9_G_A2: J4.2, P7.P$1, U2.17 (IO9)
IO10_G_A2: J4.1, P8.P$1, U2.18 (IO10)
IO11_G_D1: J5.2, P20.P$1, U2.19 (IO11)
IO12_G_D1: J5.1, P21.P$1, U2.20 (IO12)
IO13_G_D2: J6.2, P22.P$1, U2.21 (IO13)
IO14_G_D2: J6.1, P23.P$1, U2.22 (IO14)
IO15_G_A1: J3.2, P9.P$1, U2.8 (IO15)
IO16_G_A1: J3.1, P10.P$1, U2.9 (IO16)
IO17_SPI_MISO: U2.10 (IO17), U4.P$5 (LR_MISO_5)
IO18_SPI_MOSI: U2.11 (IO18), U4.P$4 (LR_MOSI_4)
IO19_UART_RX: J7.1, P17.P$1, U2.13 (IO19)
IO20_UART_TX: J7.2, P16.P$1, U2.14 (IO20)
IO21_LED: LED2.-, U2.23 (IO21)
IO38_SDA_1: J10.2, P25.P$1, R17.1, U2.31 (IO38)
IO39_SCL_1: J10.1, P26.P$1, R18.1, U2.32 (IO39)
IO40_SDA_0: J8.2, J9.2, P13.P$1, R16.1, U2.33 (IO40)
IO41_SCL_0: J8.1, J9.1, P24.P$1, R21.1, U2.34 (IO41)
LR_3V3: C12.1, C13.1, C14.1, FB2.2, U4.P$1 (VDD_3V3_1)
unnamed: J1.B5, R1.1
unnamed: J1.A5, R2.2
unnamed: Q3.1 (G), R4.1, R11.2
unnamed: R6.1, U1.1 (UD+)
unnamed: R7.1, U1.2 (UD-)
unnamed: R5.1, U8.2 (B1)
unnamed: R9.1, U8.5 (B2)
unnamed: R8.2, U1.9 (RXD)
unnamed: R10.2, U1.8 (TXD)
unnamed: LED2.+, R12.1
unnamed: L4.1, U3.3 (SW)
unnamed: LED1.+, R13.1
unnamed: C11.1, D15.2, LR_ANT.P$1, R14.2
unnamed: R19.1, R20.2, U3.5 (FB)
unnamed: R3.2, U6.5 (PROG)
RTS: R9.2, U1.6 (RTS#), U8.1 (E1)
USB_D+: J1.A6, J1.B6, P2.P$1, R6.2
USB_D-: J1.A7, J1.B7, P3.P$1, R7.2
VIN: C6.1, C7.2, D1.-, D10.-, Q3.2 (S), U3.1 (EN), U3.4 (VIN)

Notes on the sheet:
ESP32-S3-N8R8
电池及控制电路
BAT
BOOT
RST
UART Interface
GPIO Analog
GPIO Digit
I2C Interface
LR1262/LRCC68_Module
系统3V3
USB转串口_CH340K
USB_Type C
LED

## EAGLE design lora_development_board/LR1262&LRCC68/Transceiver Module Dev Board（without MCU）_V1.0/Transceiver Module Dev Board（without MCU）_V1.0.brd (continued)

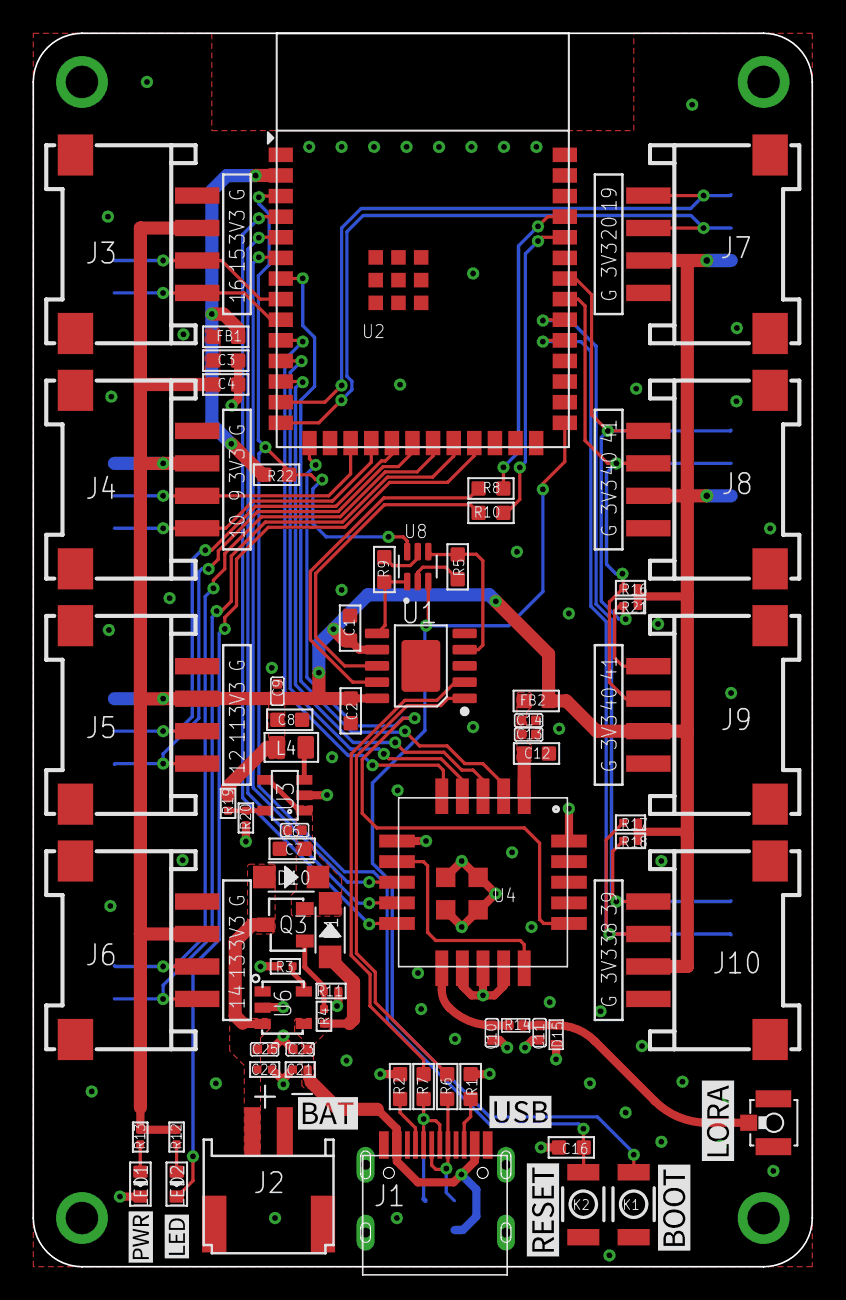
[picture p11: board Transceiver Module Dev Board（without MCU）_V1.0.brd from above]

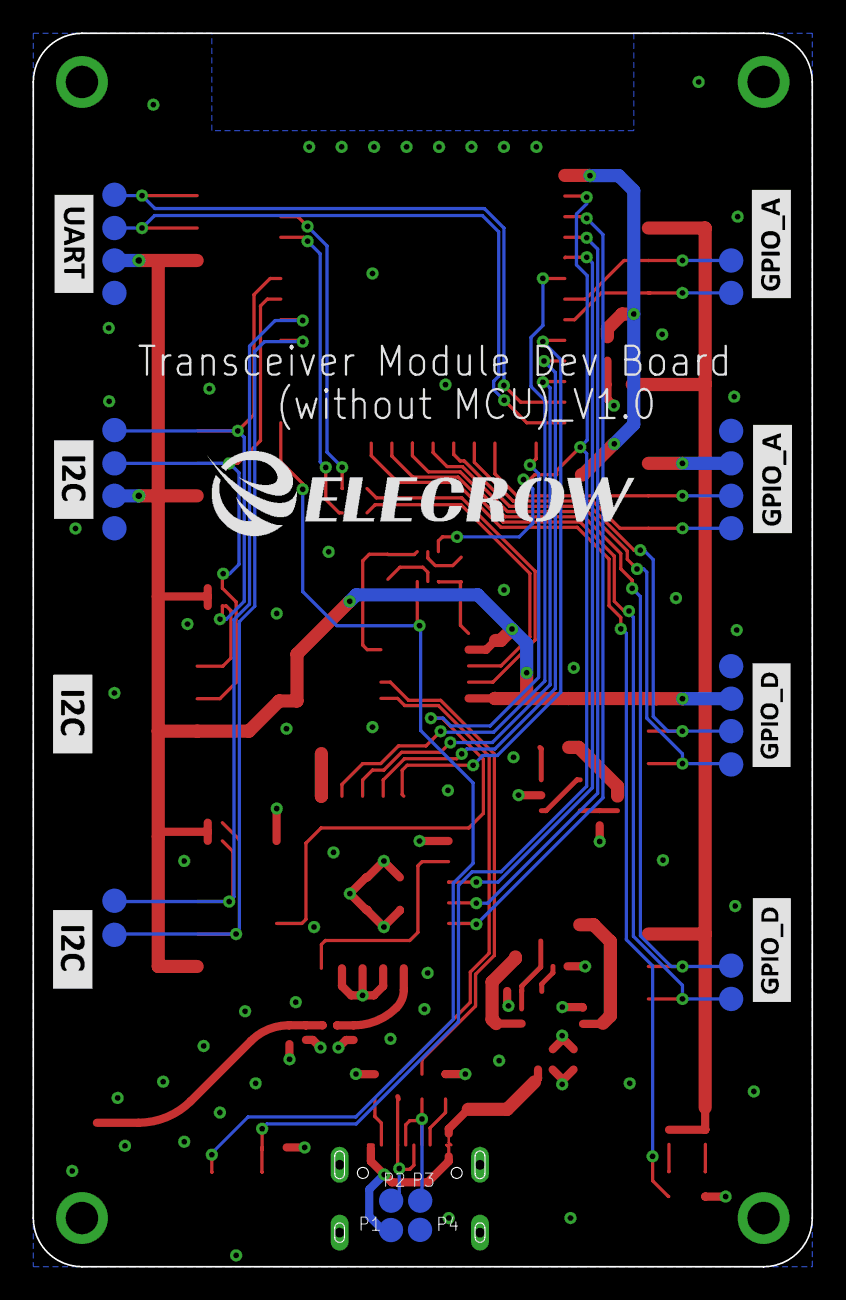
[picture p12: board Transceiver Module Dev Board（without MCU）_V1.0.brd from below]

Board: 2 copper layers, 48.0 x 76.0 mm, 93 parts (26 on the bottom side), 55 nets.

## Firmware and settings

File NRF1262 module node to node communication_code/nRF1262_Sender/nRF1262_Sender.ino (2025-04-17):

#include <Arduino.h>        // Arduino core library
#include <U8g2lib.h>        // OLED display library
#include <Wire.h>           // I2C communication library
#include <DHT20.h>         // DHT20 temperature and humidity sensor library
#include <Adafruit_TinyUSB.h>  // for Serial
#include <IRremote.h>      // Infrared receiver library
#include <RadioLib.h>      // Wireless communication library

// Display Setup
U8G2_SSD1306_128X64_NONAME_1_SW_I2C u8g2(U8G2_R0, /* clock=*/ 7, /* data=*/ 6, /* reset=*/ U8X8_PIN_NONE); // OLED display (128x64 pixels), using software I2C interface, clock pin 7, data pin 6

DHT20 dht20;

// Sensor variables
float temperature = 0;
float humidity = 0;

// LSM6DS3TR register addresses
// Defines the register addresses and sensitivity constants related to the LSM6DS3TR accelerometer for subsequent register read and write operations
#define LSM6DS3TR_ADDR 0x6B // Accelerometer I2C address
#define CTRL1_XL 0x10       // Accelerometer control register address
#define CTRL2_G  0x11       // Gyroscope control register address
#define OUTX_L_XL 0x28      // X-axis acceleration data address
#define ACCEL_SENSITIVITY 0.000122 // Accelerometer sensitivity (4g range)

// Write to a register
// This function is used to write an 8-bit value to the specified register of the LSM6DS3TR accelerometer.
// Communicates via the I2C bus. First, it starts the transmission, specifies the device address, then writes the register address and the value to be set, and finally ends the transmission.
void writeRegister(uint8_t reg, uint8_t value) {
  // 1. Start the I2C transmission and specify the accelerometer device address (0x6B)
  Wire.beginTransmission(LSM6DS3TR_ADDR);
  
  // 2. Write the address of the register to be operated on
  Wire.write(reg);
  
  // 3. Write the value to be set
  Wire.write(value);
  
  // 4. End the transmission (actually perform the write operation) - Actually perform the I2C write operation and release the I2C bus
  Wire.endTransmission();
}

// Read from a register
/*
This method is called a "repeated start condition" and is common in I2C read operations.
First, set the read pointer position, then read the data. This is a typical I2C read process.
*/
void readRegister(uint8_t reg, uint8_t *data, uint8_t length) {
  // 1. Start the I2C transmission and specify the accelerometer device address
  Wire.beginTransmission(LSM6DS3TR_ADDR);
  
  // 2. Write the address of the register to start reading from
  Wire.write(reg);
  
  // 3. End the transmission but do not release the bus (false parameter): The false parameter means to send a stop signal but do not release the bus
  Wire.endTransmission(false);
  
  // 4. Request to read the specified length of data from the device
  Wire.requestFrom(LSM6DS3TR_ADDR, length);
  
  // 5. Read the data byte by byte
  for (int i = 0; i < length; i++) {
    data[i] = Wire.read();
  }
}

// New: Define the sensor data structure
struct SensorData {
  float temperature;
  float humidity;
  float accelX;
  float accelY;
  float accelZ;
};

// Constants for button and LED control
// //This is the pin of the external device
const int buttonPin = 12;  // Button pin
const int ledPin = 26;     // LED pin
volatile bool ledState = false; // LED state flag

// IR Receiver Setup
const uint8_t IR_RECEIVER_PIN = 24;    // Infrared receiver pin

// Button and LED control setup (for debounce and state toggle)
// This is the button and LED on the board
int Button = 32;  // Button connection pin
int LED = 41;     // LED connection pin
int state = 0;    // LED state 0: OFF, 1: ON
unsigned long lastDebounceTime = 0;  // Time of the last button press
unsigned long debounceDelay = 50;    // Debounce delay (50 milliseconds)
unsigned long lastButtonPressTime = 0;
unsigned long debounceDelay2 = 200;  // 200ms debounce delay

// LoRa Setup
// Radio Setup (SX1262)
// Wireless module pins    
SX1262 radio = new Module(44, 38, 42, 43); // 44：LR_NSS   38: LR_DIO1    42:LR_NRESET    43 :LR_BUSY
volatile bool transmittedFlag = false;     // Transmission completion flag
int transmissionState = RADIOLIB_ERR_NONE; // Transmission state


// Radio transmission flag function
void setFlag(void) {
  // Automatically called when the wireless module finishes sending a packet.
  // The main loop detects that transmittedFlag is true → Processes the sending result.
  transmittedFlag = true;  // Set the transmission completion flag
}

void setup() {
  // Initialize the display
  u8g2.begin(); // Use software I2C communication (pins 7-SCL, 6-SDA), set the display resolution to 128x64 pixels

  Serial1.setPins(28, 29); // Specify pins 28 and 29 for the Serial1 communication interface. Here, it is connected to the GPS positioning module
  // Initialize serial communication
  Serial.begin(9600);    // Communicate with the computer
  Serial1.begin(9600); // Initialize Serial1 for communication    Communicate with the GPS module

  // IR_RECEIVER_PIN is the infrared receiver pin
  IrReceiver.begin(IR_RECEIVER_PIN);

  // Initialize DHT20 sensor
  Wire.setPins(13, 14);  // Set the I2C pins SDA=13, SCL=14
  Wire.begin();          // Initialize the I2C bus
  while (dht20.begin()) {  // Try to initialize the DHT20
    Serial.println("Initialize DHT20 sensor failed");
    delay(1000);
  }

  // Initialize button and LED pins
  // This group is for the external button and bulb
  pinMode(buttonPin, INPUT);      // Set the button pin as an input
  pinMode(ledPin, OUTPUT);        // Set the LED pin as an output
  // Interrupt setup: Connect the button pin (12) to an interrupt, specify the interrupt service function as toggleLED, and the trigger condition is RISING (rising edge, i.e., when the button is pressed).
  attachInterrupt(digitalPinToInterrupt(buttonPin), toggleLED, RISING); 

  // Initialize button and LED pins
  // This group is for the button and LED on the nRF1262 board
  pinMode(Button, INPUT);
  pinMode(LED, OUTPUT);
  attachInterrupt(digitalPinToInterrupt(Button), buttonISR, FALLING);


  // initialize LR1262 with default settings
  Serial.print(F("[LR1262] Initializing ... "));
  // Initialize LoRa
  // Set the SPI pins
  SPI.setPins(47, 45, 46);  // SCK=47, MISO=45, MOSI=46
  SPI.begin();
  // Initialize the wireless module
  int state = radio.begin(
    868.0,       // Frequency: 868MHz
    125.0,       // Bandwidth: 125kHz
    7,           // Spreading factor: 7
    7,           // Coding rate: 4/7
    RADIOLIB_SX126X_SYNC_WORD_PUBLIC,  // Sync word
    22,          // Output power: 22dBm
    8,           // Preamble length: 8 symbols
    3.3,         // Use TCXO
    false        // Do not use an external RF switch
  );
  if (state == RADIOLIB_ERR_NONE) {
    Serial.println(F("LoRa Initialized successfully!"));
  } else {
    Serial.print(F("LoRa initialization failed, code "));
    Serial.println(state);
    while (true) { delay(10); }
  }

  // Other configurations
  radio.setCurrentLimit(140.0);      // Set the current limit to 140mA
  radio.setPacketSentAction(setFlag); // Set the callback function to be called after the LoRa module finishes sending a packet to setFlag.

  Serial.println("IR Receiver and LoRa Setup complete.");

  transmissionState = radio.startTransmit("Hello World!"); // Start sending test data

}

void loop() {
  // // Get temperature and humidity from DHT20 sensor
  // 1. Collect sensor data
  SensorData data;
  data.temperature = dht20.getTemperature();
  data.humidity = dht20.getHumidity() * 100; // Convert to percentage
  
  // Display sensor readings on the screen
  u8g2.firstPage(); // Start a new page
  do {
    u8g2.setFont(u8g2_font_6x13_tf); // Set the font
    u8g2.setCursor(0, 30); // Set the text position
    u8g2.print("Temp: "); // Output text and data
    u8g2.print(data.temperature);
    u8g2.print("C");

    u8g2.setCursor(0, 50);
    u8g2.print("Humidity: ");
    u8g2.print(data.humidity);
    u8g2.print(" %RH");
  } while (u8g2.nextPage()); // Refresh the display page until all pages are displayed.

  // Output temperature and humidity to the Serial monitor
  Serial.print("Temperature: ");
  Serial.print(data.temperature);
  Serial.print("C");
  Serial.print("  Humidity: ");
  Serial.print(data.humidity);
  Serial.println(" %RH");

  // Read accelerometer data 
  uint8_t accelData[6];
  writeRegister(CTRL1_XL, 0x40);
  readRegister(OUTX_L_XL, accelData, 6);
  data.accelX = (int16_t)(accelData[0] | (accelData[1] << 8)) * ACCEL_SENSITIVITY * 9.80;
  data.accelY = (int16_t)(accelData[2] | (accelData[3] << 8)) * ACCEL_SENSITIVITY * 9.80;
  data.accelZ = (int16_t)(accelData[4] | (accelData[5] << 8)) * ACCEL_SENSITIVITY * 9.80;

  // 2. Build the sending string
  String payload = 
    "Temp:" + String(data.temperature, 1) + 
    ",Hum:" + String(data.humidity, 1) + 
    ",X:" + String(data.accelX, 2) +
    ",Y:" + String(data.accelY, 2) + 
    ",Z:" + String(data.accelZ, 2);
  
  // Handle Serial1 communication
  if (Serial1.available()) {
    while (Serial1.available()) {
      char incomingByte = Serial1.read();
      Serial.print(incomingByte);
    }
  }
  if (Serial.available()) {
    Serial1.write(Serial.read());
  }

  // Handle infrared signals
  if (IrReceiver.decode()) {  // Check if a valid infrared signal is received. If so, return true.
    handleIRCommand(); // Call this function to process the received infrared signal, such as printing the signal's protocol, command, and address.
    IrReceiver.resume(); // Resume() prepares to receive the next signal
  }

  // LoRa transmission logic
  // Check if the LoRa module has completed a data transmission.
  // transmittedFlag is set in the setFlag() callback function, which is triggered when the LoRa module finishes sending a packet.
  if (transmittedFlag) { // Check the transmission completion flag
    transmittedFlag = false; // If the transmission is completed, reset transmittedFlag to false.

    if (transmissionState == RADIOLIB_ERR_NONE) { // Report the transmission status (success/failure)
      Serial.println(F("transmission finished!"));
    } else {
      Serial.print(F("LoRa transmission failed, code "));
      Serial.println(transmissionState);
    }

    // 3. Send the data
    radio.finishTransmit();
    transmissionState = radio.startTransmit(payload);
    Serial.println("Sent: " + payload); // Debug output

  }
  delay(2000); // Change the sending interval to 2 seconds
}

// This function is an interrupt service function for handling button press events.
// ----This is the button on the board----
// When the button connected to the specified pin is pressed (triggering a falling edge interrupt), this function is called to toggle the LED state and handle the button debounce issue.
void buttonISR() {
  unsigned long currentMillis = millis();
  // Check if the difference between the current time and the time of the last button press is greater than the debounce delay debounceDelay (here, 50 milliseconds).
  // If the difference is greater than the debounce delay, it means the button has been pressed stably and is not a false trigger caused by jitter.
  if (currentMillis - lastDebounceTime > debounceDelay) {
    state = 1 - state; // Toggle the LED state flag variable state. If state was originally 0 (LED off), it becomes 1 (LED on), and vice versa.
    if(state == 1) {
      digitalWrite(LED, HIGH);
    } else {
      digitalWrite(LED, LOW);
    }
    lastDebounceTime = currentMillis;
  }
}

// ----This is the interrupt for the external button press----
void toggleLED() {
  unsigned long currentMillis2 = millis();
  if (currentMillis2 - lastButtonPressTime > debounceDelay2) {
    ledState = !ledState;
    digitalWrite(ledPin, ledState ? HIGH : LOW);  // Set the LED state
    lastButtonPressTime = currentMillis2;  // Update the last press time
  }
}

void handleIRCommand() {
  // Print raw IR data
  // 1. Print the title of the raw IR data
  // Print IR data only when a signal is detected
  Serial.println("\n===== IR Command Detected =====");

  // 2. Print the protocol type
  Serial.print("Protocol: ");
  Serial.println(getProtocolString(IrReceiver.decodedIRData.protocol));

  // 3. Print the command value (in hexadecimal)
  Serial.print("Hex Command: 0x");
  Serial.println(IrReceiver.decodedIRData.command, HEX);

  // 4. Print the address value (in hexadecimal)
  Serial.print("Address: 0x");
  Serial.println(IrReceiver.decodedIRData.address, HEX);

  // Print raw IR data for debugging
  // 5. Print the raw waveform data
  Serial.println("Raw IR Data:");
  IrReceiver.printIRResultRawFormatted(&Serial, true);

}

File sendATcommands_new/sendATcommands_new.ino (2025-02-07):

#include "config.h"
#include <Arduino.h>
#include "At_Config.hpp"

// Receive command data buffer
uint8_t cmd_data_buf[244] = { 0 };

// Receive command data size
uint8_t cmd_data_size = 0;

// static const uint32_t rfswitch_dio_pins[] = {
//   RADIOLIB_LR11X0_DIO5, RADIOLIB_LR11X0_DIO6,
//   RADIOLIB_NC, RADIOLIB_NC, RADIOLIB_NC
// };

// static const Module::RfSwitchMode_t rfswitch_table[] = {
//   // mode                  DIO5  DIO6
//   { LR11x0::MODE_STBY,   { LOW,  LOW  } },
//   { LR11x0::MODE_RX,     { HIGH, LOW  } },
//   { LR11x0::MODE_TX,     { HIGH, HIGH } },
//   { LR11x0::MODE_TX_HP,  { LOW,  HIGH } },
//   { LR11x0::MODE_TX_HF,  { LOW,  LOW  } },
//   { LR11x0::MODE_GNSS,   { LOW,  LOW  } },
//   { LR11x0::MODE_WIFI,   { LOW,  LOW  } },
//   END_OF_MODE_TABLE,
// };


void setup() {
  Serial.begin(115200);
  while (!Serial)
    ;           // Wait for serial to be initialised
  delay(2000);  // Give time to switch to the serial monitor
  SPI.setPins(47, 45, 46);
  SPI.begin();
  at_config.begin();
  int16_t state = 0;  // return value for calls to RadioLib
  state = radio.begin();
  debug(state != RADIOLIB_ERR_NONE, F("Initialise radio failed"), state, false);
  // radio.setRfSwitchTable(rfswitch_dio_pins, rfswitch_table);
  radio.setCurrentLimit(140.0);
  radio.setTCXO(3.3);
  Serial.println(F("\nAT Begin"));
}

void loop() {
  if (at_config.receiveSerialCmd(cmd_data_buf, &cmd_data_size)) {
    // Parsing command
    at_config.parseCmd((char *)cmd_data_buf, cmd_data_size);

    // Clear buffer & size
    memset(cmd_data_buf, 0, cmd_data_size);
    cmd_data_size = 0;
  }
  ParameterSetting();
}

void ParameterSetting() {
  if (ABP_Join_Flag == 1) {
    ABP_Join_Flag = 0;
    Serial.println("");
    Serial.println("Join ABP");
    int16_t state = 0;
    uint8_t joinDR = 0;
    //LoRaWAN v1.1
    //node.beginABP(app_param.lora_info.JoinEui, app_param.lora_info.FnwksKey, app_param.lora_info.SnwksKey, app_param.lora_info.NwkSKey, app_param.lora_info.AppSKey);
    //LoRaWAN v1.0.3
    node.beginABP(app_param.lora_info.DevAddr, NULL, NULL, app_param.lora_info.NwkSKey, app_param.lora_info.AppSKey);
    node.activateABP(joinDR);
    debug(state != RADIOLIB_ERR_NONE, F("Activate ABP failed"), state, false);
  }
  if (OTAA_Join_Flag == 1) {
    OTAA_Join_Flag = 0;
    Serial.println("");
    Serial.println("Join OTAA");
    int16_t state = 0;

    uint8_t joinDR = 0;
    if (app_param.lora_info.ActiveRegion == 0) {
      joinDR = 2;
    } else {
      joinDR = 0;
    }

    //LoRaWAN v1.1
    //node.beginOTAA(app_param.lora_info.JoinEui, app_param.lora_info.DevEui, app_param.lora_info.NwkKey, app_param.lora_info.AppKey);
    //LoRaWAN v1.0.3
    node.beginOTAA(app_param.lora_info.JoinEui, app_param.lora_info.DevEui, NULL, app_param.lora_info.AppKey);
    Serial.println("Join ('login') the LoRaWAN Network");
    state = node.activateOTAA(joinDR);
    debug(state != RADIOLIB_LORAWAN_NEW_SESSION, F("Join failed"), state, false);
    Serial.print("[LoRaWAN] DevAddr: ");
    Serial.println((unsigned long)node.getDevAddr(), HEX);
    if (app_param.lora_info.ADR == 1) {
      node.setADR(true);
    } else {
      node.setADR(false);
    }
    node.setDatarate(app_param.lora_info.DR);
    if (app_param.lora_info.dutyCycleEnabled == 1) {
      node.setDutyCycle(true, app_param.lora_info.msPerHour);
    } else {
      node.setDutyCycle(false, app_param.lora_info.msPerHour);
    }
    node.setDwellTime(true, 400);
  }

  if (Send_Flag == 1) {
    Send_Flag = 0;
    if (app_param.lora_info.ActivationType == 1)  //ABP
    {
      Serial.println("Send ABP OK");
      int state = node.sendReceive(MsgTemp, sizeof(MsgTemp));
      debug(state < RADIOLIB_ERR_NONE, F("Error in sendReceive"), state, false);

      // Check if a downlink was received
      // (state 0 = no downlink, state 1/2 = downlink in window Rx1/Rx2)
      if (state > 0) {
        Serial.println(F("Received a downlink"));
      } else {
        Serial.println(F("No downlink received"));
      }
    }
    if (app_param.lora_info.ActivationType == 2)  //OTAA
    {
      int16_t state = RADIOLIB_ERR_NONE;
      Serial.println("Send OTAA OK");
      uint8_t downlinkPayload[10];
      size_t downlinkSize;
      LoRaWANEvent_t uplinkDetails;
      LoRaWANEvent_t downlinkDetails;
      // uint8_t data[] = {0x1, 0x2, 0x3, 0x4};
      if (Ack_State == 1) {
        Serial.println(F("and requesting LinkCheck and DeviceTime"));
        node.sendMacCommandReq(RADIOLIB_LORAWAN_MAC_LINK_CHECK);
        node.sendMacCommandReq(RADIOLIB_LORAWAN_MAC_DEVICE_TIME);
        // state = node.sendReceive(MsgTemp, Port_Number, downlinkPayload, &downlinkSize, true, &uplinkDetails, &downlinkDetails);

         state = node.sendReceive(MsgTemp, MsgTemp_size -1, Port_Number, downlinkPayload, &downlinkSize, true, &uplinkDetails, &downlinkDetails);
      } else {
        // state = node.sendReceive(MsgTemp, Port_Number, downlinkPayload, &downlinkSize, false, &uplinkDetails, &downlinkDetails);

        state = node.sendReceive(MsgTemp, MsgTemp_size -1, Port_Number, downlinkPayload, &downlinkSize, true, &uplinkDetails, &downlinkDetails);
      }
      debug(state < RADIOLIB_ERR_NONE, F("Error in sendReceive"), state, false);
      if (state > 0) {
        Serial.println(F("Received a downlink"));
        if (downlinkSize > 0) {
          Serial.println(F("Downlink data: "));
          arrayDump(downlinkPayload, downlinkSize);
        } else {
          Serial.println(F("<MAC commands only>"));
        }
      } else {
        Serial.println(F("[LoRaWAN] No downlink received"));
      }
    }
  }
  if (ADR_set_Flag == 1) {
    ADR_set_Flag = 0;
    if (app_param.lora_info.ADR == 1) {
      node.setADR(true);
    } else {
      node.setADR(false);
    }
  }
  if (DR_set_Flag == 1) {
    DR_set_Flag = 0;
    node.setDatarate(app_param.lora_info.DR);
  }
  if (DCS_set_Flag == 1) {
    DCS_set_Flag = 0;
    if (app_param.lora_info.dutyCycleEnabled) {
      node.setDutyCycle(true, app_param.lora_info.msPerHour);
    } else {
      node.setDutyCycle(false, app_param.lora_info.msPerHour);
    }
  }
  if (TXP_set_Flag == 1) {
    TXP_set_Flag = 0;
    node.setTxPower(app_param.lora_info.txPower);
  }
  if (RX2DR_set_Flag == 1) {
    RX2DR_set_Flag = 0;
    node.setRx2Dr(app_param.lora_info.rx2dr);
  }
  if (Band_set_Flag == 1) {
    Band_set_Flag = 0;
    if (app_param.lora_info.ActiveRegion == 0) {
      Serial.println(F("Set Regional Choices EU868"));
      node = LoRaWANNode(&radio, &Region_868, subBand);
    } else if (app_param.lora_info.ActiveRegion == 1) {
      Serial.println(F("Set Regional Choices US915"));
      node = LoRaWANNode(&radio, &Region_915, subBand);
    }
  }
}
